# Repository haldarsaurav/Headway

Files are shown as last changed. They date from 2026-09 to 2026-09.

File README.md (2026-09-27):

<p align="center">HEADWAY — a small window on the day</p>

<p align="center"><strong>Train and bus departures, the last few hours at the station, and the weather before I leave home.</strong></p>

## Find your way around

| See it | Build it |
| :--- | :--- |
| **[Screens and five looks →](#take-a-look)** | **[First setup →](#first-setup-in-plain-steps)** |
| **[Photos and video clips →](#the-board-in-use)** | **[FreeCAD cases →](#the-two-cases)** |
| **[Data flow →](#how-it-works)** | **[Wiring and pinout →](#wiring-and-pinout)** |
| **[Electricity use →](#electricity-use)** | **[Reuse and permissions →](#current-state-and-rights)** |

The [screen and icon guide](docs/FEATURE_GUIDE.md) goes page by page. [Firmware and tests](https://github.com/haldarsaurav/Headway_code) live in the code repository.

## Why I built Headway

because why not? 😁

It is a 3.2-inch ILI9341 screen driven by an ESP32-C3 Super Mini. One tap on the board's BOOT button moves to the next page. A three-second hold opens setup. The board reads transport data through [Transitous](https://transitous.org/) and weather from [Open-Meteo](https://open-meteo.com/); it is an independent personal build, not an official operator display.

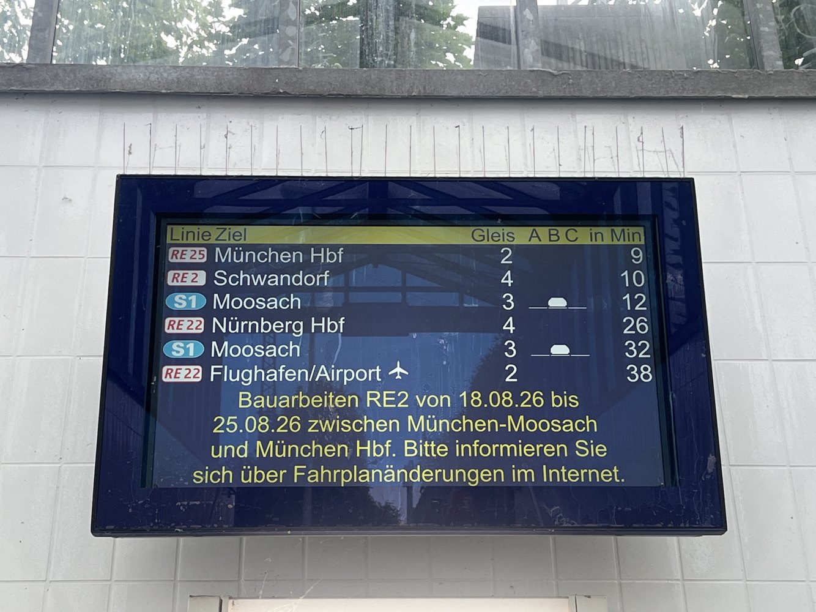
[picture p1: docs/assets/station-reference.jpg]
A real departure board at Freising station that inspired Headway
<p align="center"><br><sub>Sign at my Bahnhof.</sub></p>

## The board in use

The first photo is a powered prototype, photographed at home. It is useful to finally see the physical thing beside the station and weather glances that prompted the project. The second is the same build after dark; these are phone photos, while the crisp screen galleries below are software renders.

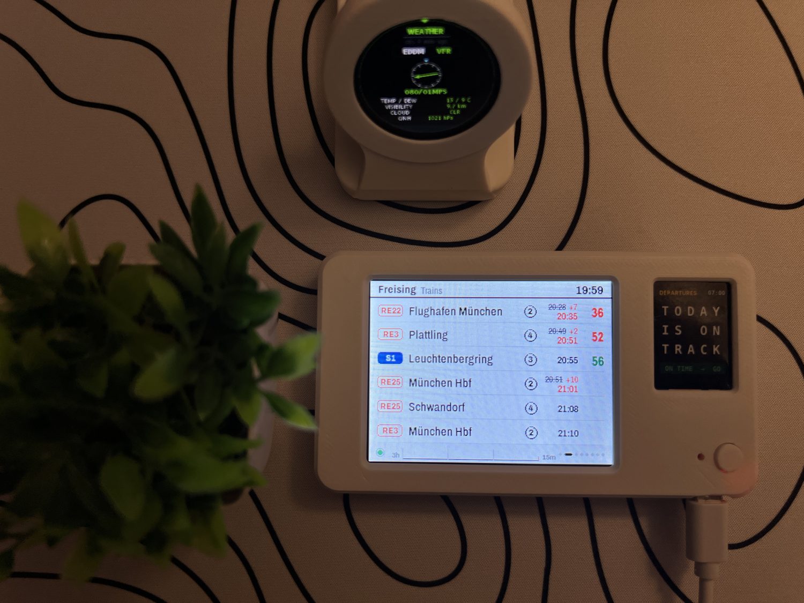
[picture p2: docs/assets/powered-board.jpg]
Powered Headway prototype showing train departures at home
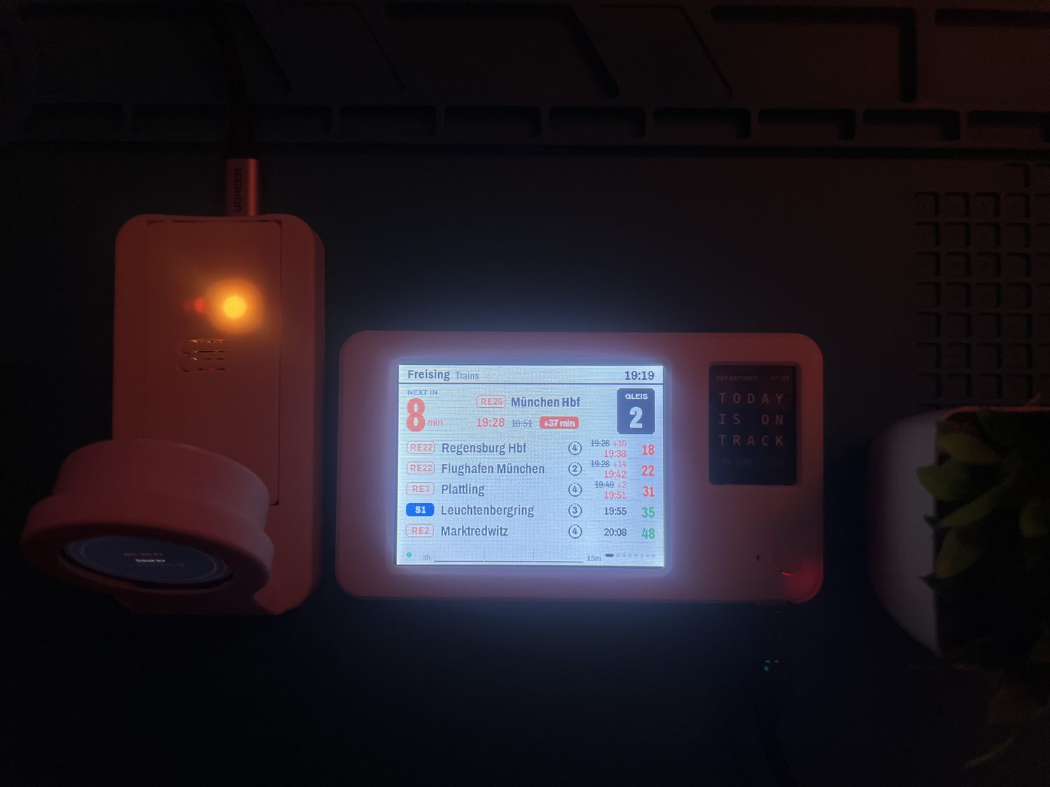
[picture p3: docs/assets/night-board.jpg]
Powered Headway prototype showing departures after dark


The phone videos show all five looks on the powered board, moving from trains to buses and weather. [Play the silent clips](docs/index.html#photos) or open a look directly: [Original](docs/assets/headway-original.webm), [Bahnsteig](docs/assets/headway-bahnsteig.webm), [Amber Matrix](docs/assets/headway-amber-matrix.webm), [Papier](docs/assets/headway-papier.webm), [Split-Flap](docs/assets/headway-split-flap.webm). These are short, compressed excerpts; the full-resolution MOV recordings remain outside this repository.

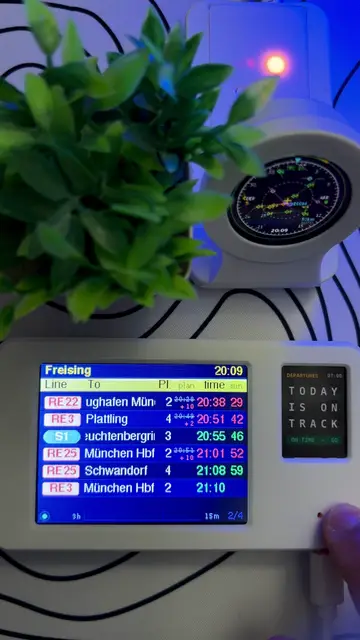
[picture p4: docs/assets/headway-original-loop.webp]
Original look moving through pages on the physical Headway board
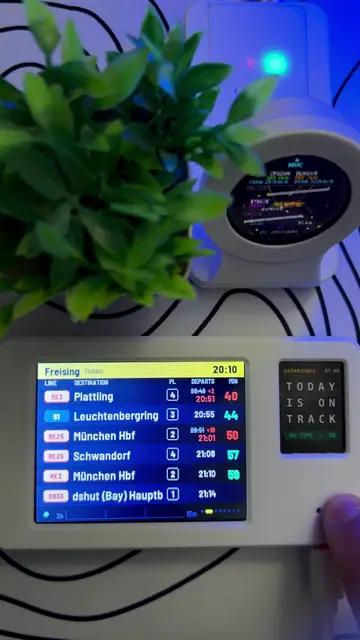
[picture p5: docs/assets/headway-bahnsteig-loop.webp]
Bahnsteig look moving through pages on the physical Headway board
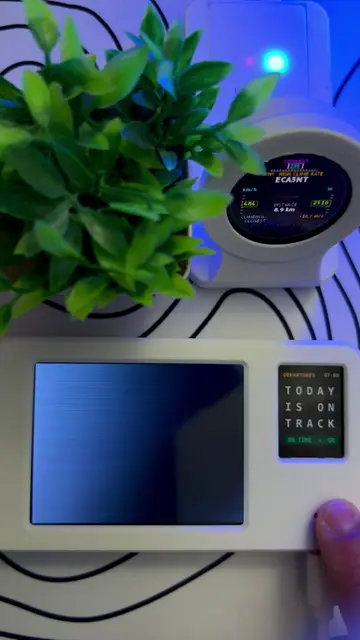
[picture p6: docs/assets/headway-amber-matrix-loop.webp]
Amber Matrix look moving through pages on the physical Headway board
<p align="center">  <br><sub>Original · Bahnsteig · Amber Matrix</sub></p>
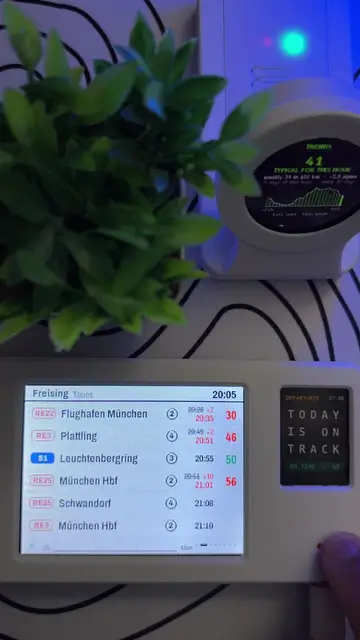
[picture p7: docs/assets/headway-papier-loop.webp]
Papier look moving through pages on the physical Headway board
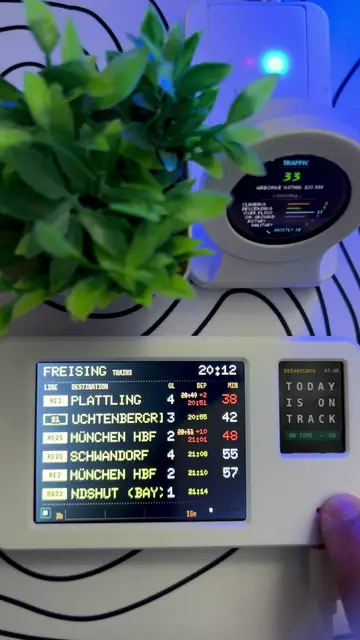
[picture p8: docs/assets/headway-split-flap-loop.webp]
Split-Flap look moving through pages on the physical Headway board
<p align="center"> <br><sub>Papier · Split-Flap</sub></p>

## Take a look

The [screen gallery](docs/index.html#screens) lets you switch **five looks** and the train, bus, weather, outlook and device-setup screens. Its preview images were rendered from the actual drawing code with sample data, not photographed from hardware. Most gallery images are from firmware 1.2.6. Firmware 1.2.7 changed delay-history restart behaviour; 1.2.8 changes the small temperature-history graph on the outlook page, shown separately below.

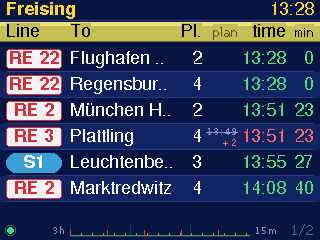
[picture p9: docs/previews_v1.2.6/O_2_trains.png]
Original look train departures
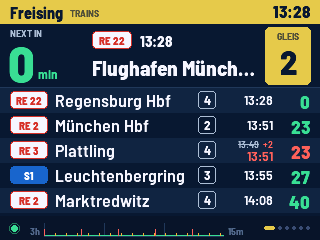
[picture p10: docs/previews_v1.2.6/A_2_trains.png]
Bahnsteig look train departures
<p align="center"> <br><sub>Original and Bahnsteig, using the same sample departures.</sub></p>

<details><summary>Original — the first platform-sign layout</summary>

<p align="center">Original train board software preview<br><sub>Original · train board · sample data</sub></p>

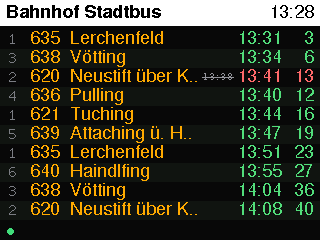
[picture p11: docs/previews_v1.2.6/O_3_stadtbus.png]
Original town bus software preview
<p align="center"><br><sub>Original · town bus · sample data</sub></p>

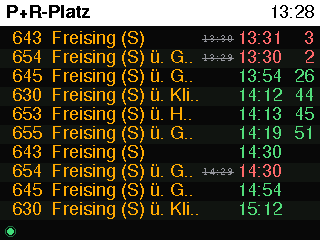
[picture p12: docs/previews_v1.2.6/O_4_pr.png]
Original P+R bus software preview
<p align="center"><br><sub>Original · P+R bus · sample data</sub></p>

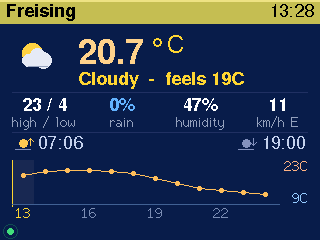
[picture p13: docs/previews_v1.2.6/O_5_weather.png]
Original weather now software preview
<p align="center"><br><sub>Original · weather now · sample data</sub></p>

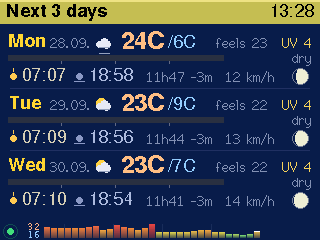
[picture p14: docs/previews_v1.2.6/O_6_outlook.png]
Original three-day outlook software preview
<p align="center"><br><sub>Original · three-day outlook · sample data</sub></p>

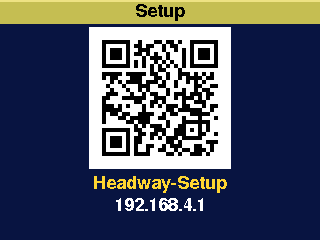
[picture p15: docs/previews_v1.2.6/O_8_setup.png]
Original device setup software preview
<p align="center"><br><sub>Original · device setup · sample data</sub></p>

</details>

<details><summary>Bahnsteig — navy and signal yellow</summary>

<p align="center">Bahnsteig train board software preview<br><sub>Bahnsteig · train board · sample data</sub></p>

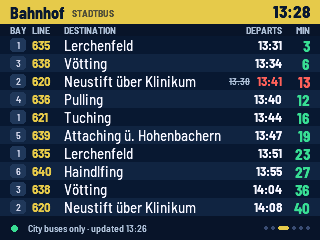
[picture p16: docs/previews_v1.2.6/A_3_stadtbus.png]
Bahnsteig town bus software preview
<p align="center"><br><sub>Bahnsteig · town bus · sample data</sub></p>

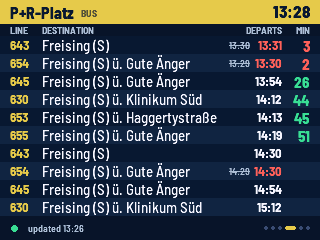
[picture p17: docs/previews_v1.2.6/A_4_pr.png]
Bahnsteig P+R bus software preview
<p align="center"><br><sub>Bahnsteig · P+R bus · sample data</sub></p>

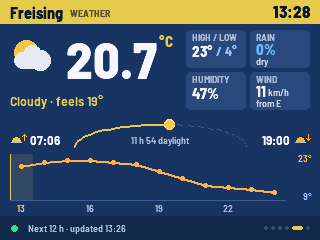
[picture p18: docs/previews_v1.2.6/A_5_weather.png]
Bahnsteig weather now software preview
<p align="center"><br><sub>Bahnsteig · weather now · sample data</sub></p>

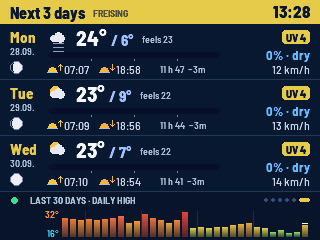
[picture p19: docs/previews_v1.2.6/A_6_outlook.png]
Bahnsteig three-day outlook software preview
<p align="center"><br><sub>Bahnsteig · three-day outlook · sample data</sub></p>

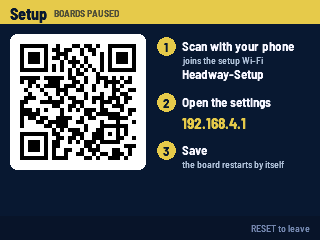
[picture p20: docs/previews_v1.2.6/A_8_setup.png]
Bahnsteig device setup software preview
<p align="center"><br><sub>Bahnsteig · device setup · sample data</sub></p>

</details>

<details><summary>Amber Matrix — electronic display dots</summary>

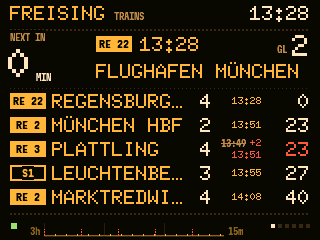
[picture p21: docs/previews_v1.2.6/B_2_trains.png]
Amber Matrix train board software preview
<p align="center"><br><sub>Amber Matrix · train board · sample data</sub></p>

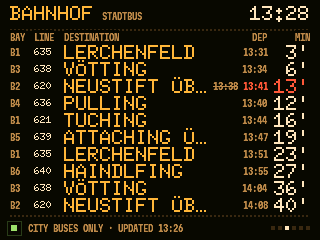
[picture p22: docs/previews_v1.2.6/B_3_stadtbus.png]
Amber Matrix town bus software preview
<p align="center"><br><sub>Amber Matrix · town bus · sample data</sub></p>

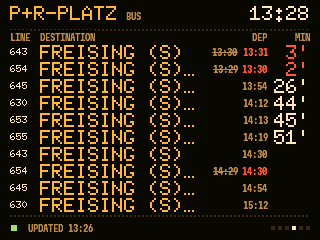
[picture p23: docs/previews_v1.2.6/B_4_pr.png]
Amber Matrix P+R bus software preview
<p align="center"><br><sub>Amber Matrix · P+R bus · sample data</sub></p>

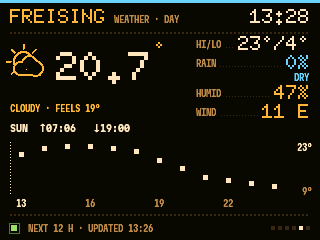
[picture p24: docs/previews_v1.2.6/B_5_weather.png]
Amber Matrix weather now software preview
<p align="center"><br><sub>Amber Matrix · weather now · sample data</sub></p>

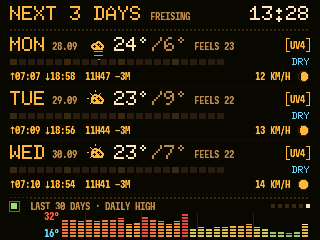
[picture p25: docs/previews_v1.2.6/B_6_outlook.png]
Amber Matrix three-day outlook software preview
<p align="center"><br><sub>Amber Matrix · three-day outlook · sample data</sub></p>

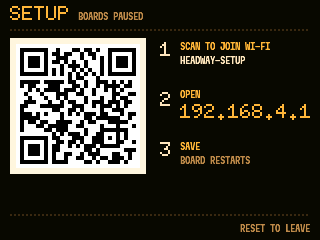
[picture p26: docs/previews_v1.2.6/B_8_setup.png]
Amber Matrix device setup software preview
<p align="center"><br><sub>Amber Matrix · device setup · sample data</sub></p>

</details>

<details><summary>Papier — light paper and ink</summary>

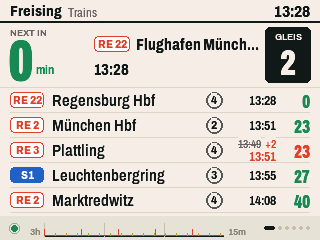
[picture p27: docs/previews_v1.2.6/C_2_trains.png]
Papier train board software preview
<p align="center"><br><sub>Papier · train board · sample data</sub></p>

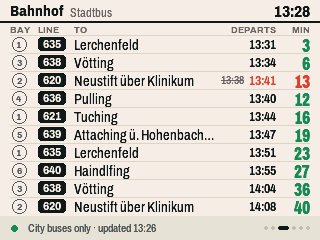
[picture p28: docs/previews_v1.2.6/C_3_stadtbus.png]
Papier town bus software preview
<p align="center"><br><sub>Papier · town bus · sample data</sub></p>

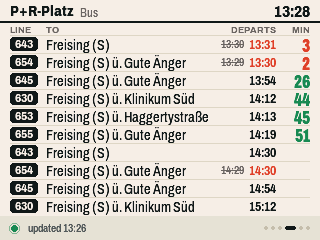
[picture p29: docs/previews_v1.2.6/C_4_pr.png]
Papier P+R bus software preview
<p align="center"><br><sub>Papier · P+R bus · sample data</sub></p>

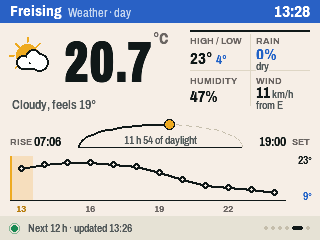
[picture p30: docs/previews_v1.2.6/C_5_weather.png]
Papier weather now software preview
<p align="center"><br><sub>Papier · weather now · sample data</sub></p>

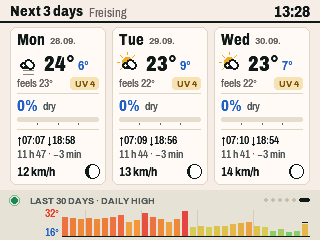
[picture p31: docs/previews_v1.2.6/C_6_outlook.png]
Papier three-day outlook software preview
<p align="center"><br><sub>Papier · three-day outlook · sample data</sub></p>

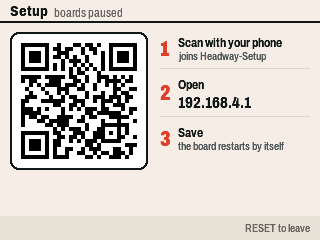
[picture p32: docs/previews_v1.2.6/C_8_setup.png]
Papier device setup software preview
<p align="center"><br><sub>Papier · device setup · sample data</sub></p>

</details>

<details><summary>Split-Flap — mechanical tile lettering</summary>

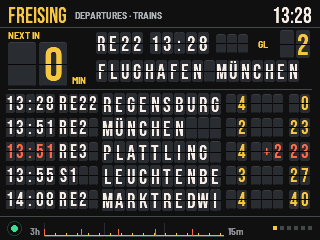
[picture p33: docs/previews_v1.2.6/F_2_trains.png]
Split-Flap train board software preview
<p align="center"><br><sub>Split-Flap · train board · sample data</sub></p>

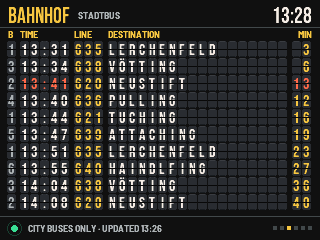
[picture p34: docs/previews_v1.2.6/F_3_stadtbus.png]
Split-Flap town bus software preview
<p align="center"><br><sub>Split-Flap · town bus · sample data</sub></p>

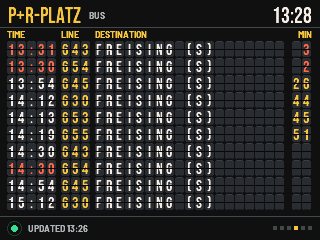
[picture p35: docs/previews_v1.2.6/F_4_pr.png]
Split-Flap P+R bus software preview
<p align="center"><br><sub>Split-Flap · P+R bus · sample data</sub></p>

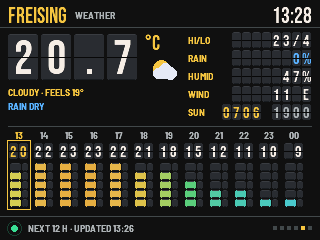
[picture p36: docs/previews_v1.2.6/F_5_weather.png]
Split-Flap weather now software preview
<p align="center"><br><sub>Split-Flap · weather now · sample data</sub></p>

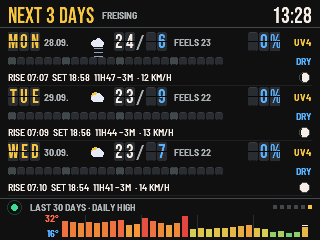
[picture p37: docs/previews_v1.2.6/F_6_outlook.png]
Split-Flap three-day outlook software preview
<p align="center"><br><sub>Split-Flap · three-day outlook · sample data</sub></p>

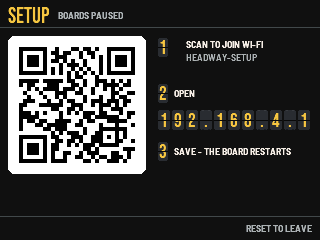
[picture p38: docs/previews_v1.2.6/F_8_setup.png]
Split-Flap device setup software preview
<p align="center"><br><sub>Split-Flap · device setup · sample data</sub></p>

</details>

The page order is **trains → Bahnhof Stadtbus → P+R-Platz → weather now → three-day outlook**. Trains can occupy one to four screens depending on the returned services. Automatic page changes and scrolling long destinations are separate, optional settings. The [full guide](docs/FEATURE_GUIDE.md) explains every badge, time, colour, icon, graph mark, status message and control with examples.

### Temperature history in 1.2.8

The graph at the bottom of the three-day outlook now draws a bar from **each day's low to its high**. The two numbers beside it are the coldest low and warmest high in the displayed window. A day with no reported low becomes a short mark at its high. This comparison uses current PC renders with sample weather data; the phone videos above show the physical board running earlier screens.

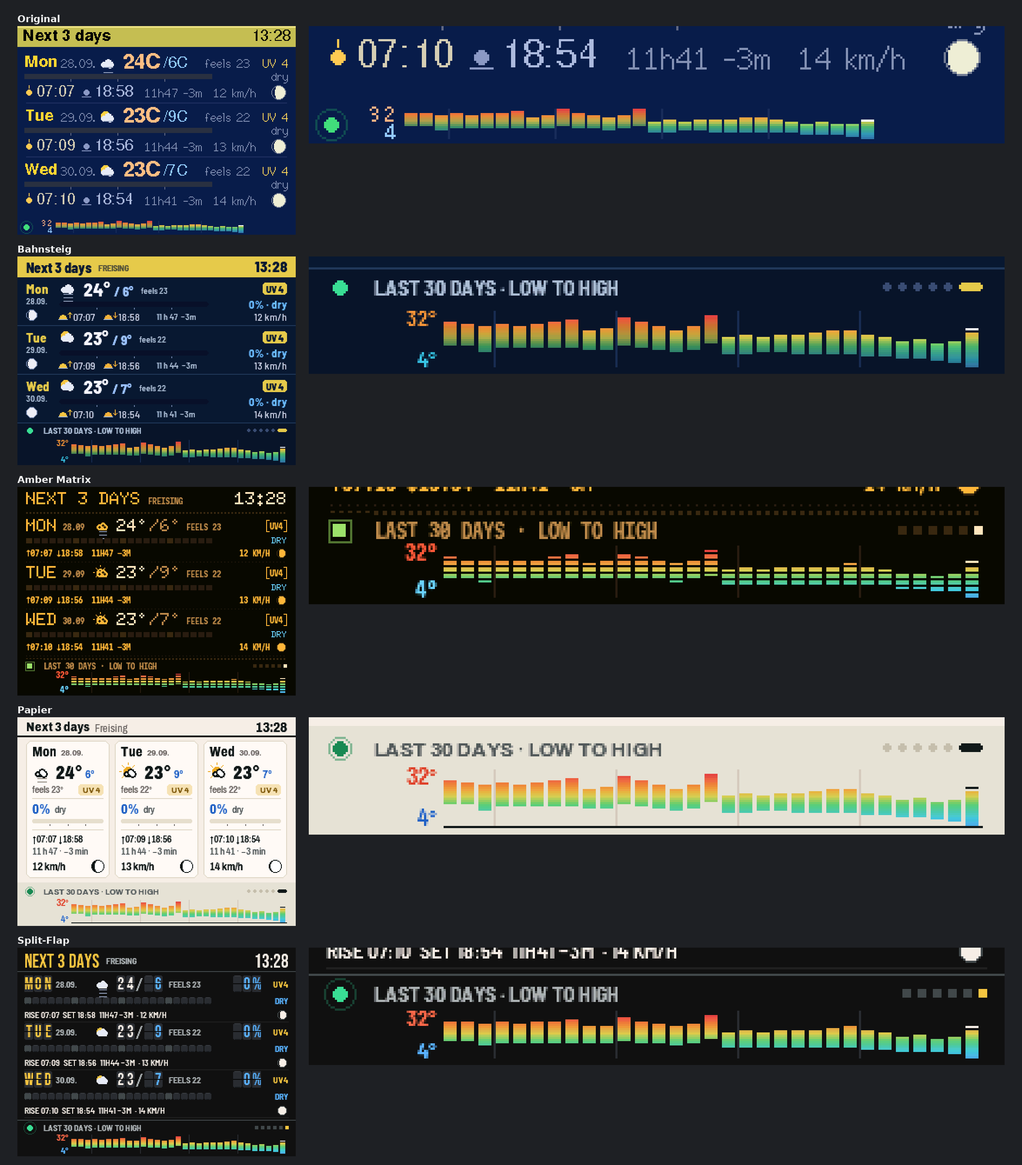
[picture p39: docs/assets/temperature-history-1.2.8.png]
Firmware 1.2.8 low-to-high temperature history shown in all five Headway looks
<p align="center"><br><sub>The updated outlook graph in all five looks. Click for the full-size image.</sub></p>

### The history strip

The train footer shows 180 elapsed-minute slots. It averages positive reported lateness among comparable realtime departures due within the next hour of each fetched board. Red marks show cancellations separately; grey marks warn of incomplete realtime coverage; gaps mean no usable sample. It is a quick view of recent feed reports, not a station-wide punctuality score. Since firmware 1.2.7 the strip survives a software restart, with a gap for the restart, but loses its history when power is removed. [Read the graph definition](docs/DELAY_GRAPH.md).

## How it works

```mermaid
flowchart TD
    T[Transitous<br/>trains and local buses] --> E[ESP32-C3<br/>fetch and validate]
    W[Open-Meteo<br/>weather and forecast] --> E
    E --> H{Each feed healthy?}
    H -->|Fresh data| S[Draw page and update history]
    H -->|Unavailable or incomplete| G[Show feed state and keep graph gaps]
    S --> D[3.2-inch screen<br/>one-button navigation]
    G --> D
    B[BOOT button<br/>hold 3 seconds] --> P[Setup portal]
    P -->|Save and restart| E
```

The feeds have separate health states. A working weather refresh cannot hide a failed train refresh. During an outage, countdowns still advance and expired rows disappear; retained readings may become stale. [Status and remaining hardware checks](docs/PROJECT_STATUS.md).

## First setup, in plain steps

1. Power the board by USB-C. On first use, scan the on-screen QR to join **Headway-Setup**.
2. Scan the settings QR or open **http://192.168.4.1/** on that Wi-Fi network.
3. Choose a 2.4 GHz network, automatic or typed weather town, one of the five looks, and optional page changes and scrolling. Press **Save and restart**.
4. Tap BOOT for the next page; hold it for three seconds to reopen setup. Hold it only after startup, because GPIO 9 is a boot strap pin.

The portal presents its controls in separate cards:

- **Wi-Fi:** choose a scanned 2.4 GHz network or type its name; leaving the password empty keeps the saved one for the same network.
- **Weather place:** detect an approximate location from the connection, or enter a town. The Freising transport stops stay fixed.
- **Look:** Original is the default; the other four choices preview immediately in the portal, then apply to the board after Save.
- **Pages and names:** automatic page changes and destination scrolling are independent and off by default; set the page interval when automatic changes are on.
- **Save and restart:** stores the settings and restarts. The delay graph keeps recent readings across that software restart, leaving a gap while setup was open.
- **Start over:** asks a second time, then forgets Wi-Fi and every setting and empties the history.

The [feature guide](docs/FEATURE_GUIDE.md#boot-controls-and-setup) covers the QR screens, controls and troubleshooting.

## The two cases

**Model A · wall, Rev9.** The slim case is meant for the morning route through the home. **Model B · desk, rev2.** The separate stand tips the screen back 15°; USB-C enters from the right. Both current designs use four M2.5 heat-set inserts and four countersunk screws. Using threaded inserts was a first for me; I wanted a back I could open without wearing out a plastic screw hole. I have a powered prototype in a printed enclosure now; the exact fit of the latest CAD revisions still needs checking.

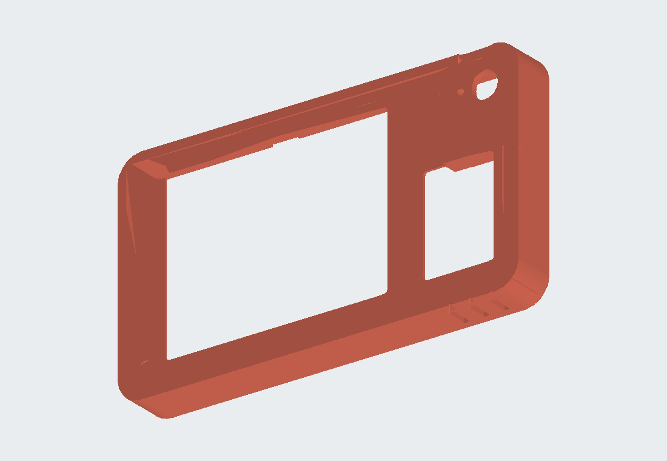
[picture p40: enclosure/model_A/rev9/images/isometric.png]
Model A wall case isometric CAD view
<p align="center"> Model B desk case isometric CAD view<br><sub>Current shell geometry rendered from the FreeCAD exports, not physical-product photos.</sub></p>

### On the slicer bed

These are actual slicer screenshots: Model A has the shell and back plate, while Model B also has its separate desk stand. The orange lines are sliced layers, not a photo of the print.

<p align="center">Model A shell and back plate arranged in a slicer Model B shell, back plate and stand arranged in a slicer<br><sub>Model A · wall / Model B · desk</sub></p>

[Full-size Model A slicer screenshot](enclosure/slicer/modelA.png) · [Full-size Model B slicer screenshot](enclosure/slicer/modelB.png)

Both have [isometric, front, back, top and side views](enclosure/README.md), plus back-plate views and a separate stand view for Model B. The [FreeCAD sources and printable parts](enclosure/README.md) are kept with each model. These photos show printed revisions and the loose parts before assembly; they do not prove the latest CAD fit.

<p align="center">Headway case parts on the printer bed under warm light Six printed Headway shell revisions laid out on a blue mat Headway enclosure, display, ESP32-C3 and fasteners before assembly<br><sub>Print in progress, revisions, and the parts laid out before assembly.</sub></p>

The close assembly photo shows **three brass heat-set inserts visible in the front shell**, beside the wired ESP32-C3, display and screws. That small hardware detail is new territory for me, and it makes the enclosure easier to open again.

<p align="center">Close assembly view showing three brass threaded inserts in the printed front shell, ESP32-C3, display and screws<br><sub>The threaded inserts are visible in the white front shell.</sub></p>

## Wiring and pinout

The circuit is two boards and nine wires. The display uses the C3's 3V3, GND, 5V and GPIO 3/4/5/6/7/10; BOOT on GPIO 9 is the control. [Pinout diagram and wiring table](docs/SCHEMATIC.md) · [ESP32-C3 module datasheet](https://documentation.espressif.com/esp32-c3-mini-1_datasheet_en.html) · [MSP3218 display manual and pinout](https://www.lcdwiki.com/res/MSP3218/3.2inch_SPI_Module_MSP3218_User_Manual_EN.pdf). Check the labels on your actual boards before powering them; Super Mini variants differ. The project drawing uses 5 V on the display LED pin, while the MSP3218 manual describes 3.3 V for always-on backlighting, so verify that connection on the exact module.

## Electricity use

| Assumption | Estimate for continuous use |
| :--- | ---: |
| Average draw | **0.75 W** |
| Energy over 24 hours | **0.018 kWh** |
| Energy over one year | **6.57 kWh** |
| At an example €0.30/kWh | **about €1.97/year** |

These are estimates, not a documented power-meter reading for this revision. A USB meter check is still on my list; the price example excludes standing charges.

## Current state and rights

Firmware **1.2.8** is in the [code repository](https://github.com/haldarsaurav/Headway_code), along with tests, preview tooling, build instructions and the changelog. The source project reports PC renders of every look and regression checks; the nine setup scenarios passed again in this repository sync. I have not compiled or flashed 1.2.8 on the ESP32 here. The current CAD also needs a full fit check. See [project status](docs/PROJECT_STATUS.md) for the precise scope.

Copyright 2026 **Saurav Haldar**. This public repository is for viewing the project. Use and reuse require permission under the [licence](LICENSE); the [permission guide](docs/PERMISSIONS.md) explains the request process. Third-party transport, weather and font material retains its own terms.

Please do not scrape the writing, diagrams, images, CAD, code or documented project plan into AI datasets or use them to recreate Headway without my written permission. The [AI-use policy](AI_POLICY.md) gives the full request path and its legal limits.

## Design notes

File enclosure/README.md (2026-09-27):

# The two Headway cases

[Back to the project](../README.md) · [Interactive CAD gallery](../docs/index.html#enclosures)

Both current designs come from editable FreeCAD models. The gallery images below were rendered from those models' exported STL geometry. They show the design, not an assembled or fit-verified device. The [main README](../README.md#the-two-cases) also shows real print iterations and the parts before assembly; its [powered-board photos](../README.md#the-board-in-use) show a physical prototype, without proving the latest CAD revision fits.

## Model A · wall, Rev9

This is the case I plan to place near my bathroom mirror or by the front door. It has a display window, a small picture-card opening and access to the BOOT key. Rev9 adds a fourth screw boss and stronger ESP32 ribs. Four M2.5 heat-set inserts and countersunk screws make the back removable. The three display screws also clamp the display; the fourth closes the far corner.

<p align="center">Model A isometric CAD view<br><sub>Isometric front shell</sub></p>

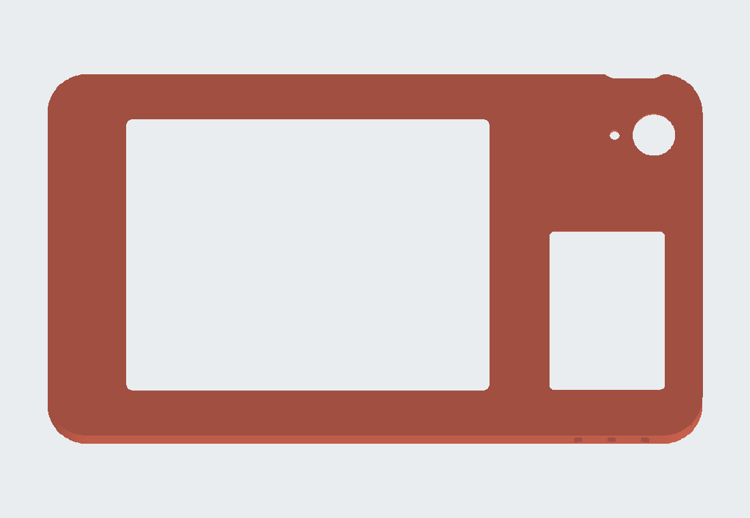
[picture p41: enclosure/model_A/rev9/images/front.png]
Model A front CAD view
<p align="center"><br><sub>Front</sub></p>
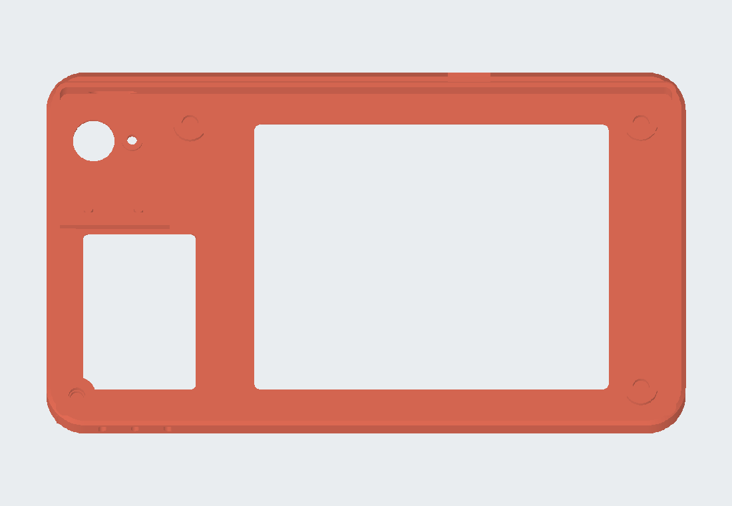
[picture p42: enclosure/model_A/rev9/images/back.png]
Model A back CAD view
<p align="center"><br><sub>Back / inside of shell</sub></p>
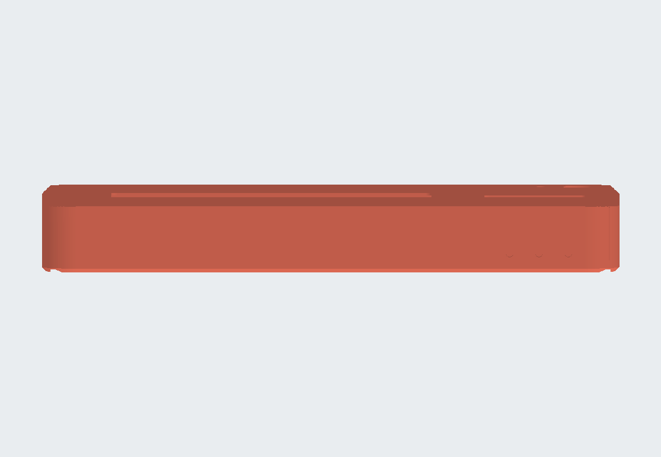
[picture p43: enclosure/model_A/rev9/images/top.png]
Model A top CAD view
<p align="center"><br><sub>Top</sub></p>
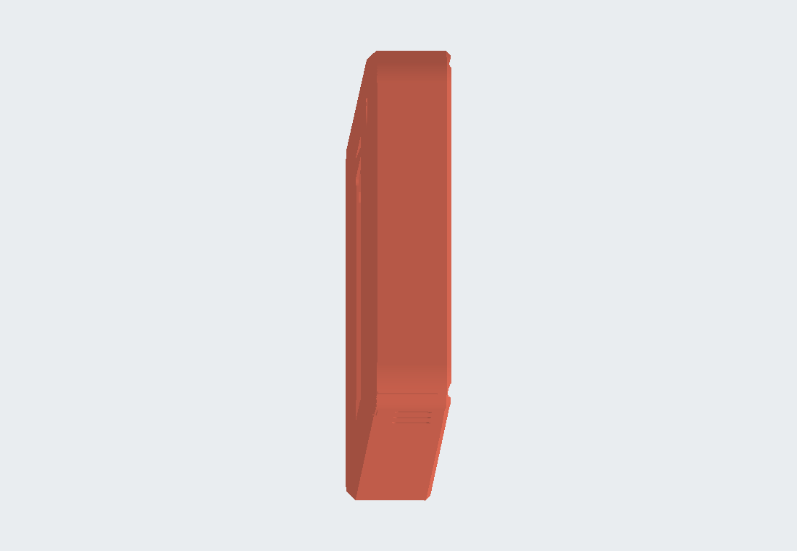
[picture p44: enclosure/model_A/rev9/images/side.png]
Model A side CAD view
<p align="center"><br><sub>Side</sub></p>
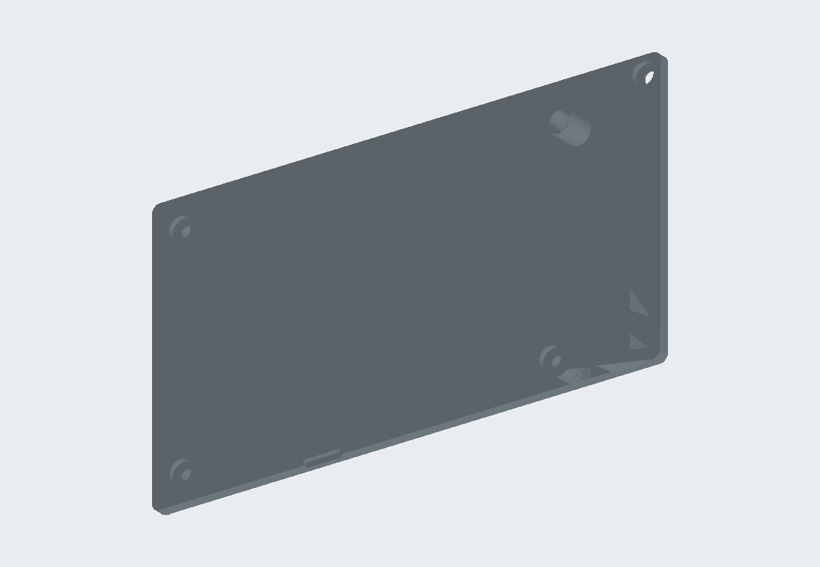
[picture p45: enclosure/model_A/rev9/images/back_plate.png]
Model A separate back plate CAD view
<p align="center"><br><sub>Separate back plate</sub></p>

[FreeCAD model](model_A/rev9/Headway_enclosure_rev9.FCStd) · [STEP](model_A/rev9/Headway_enclosure_rev9.step) · [parts, print orientation and assembly](model_A/rev9/README_REV9.md)

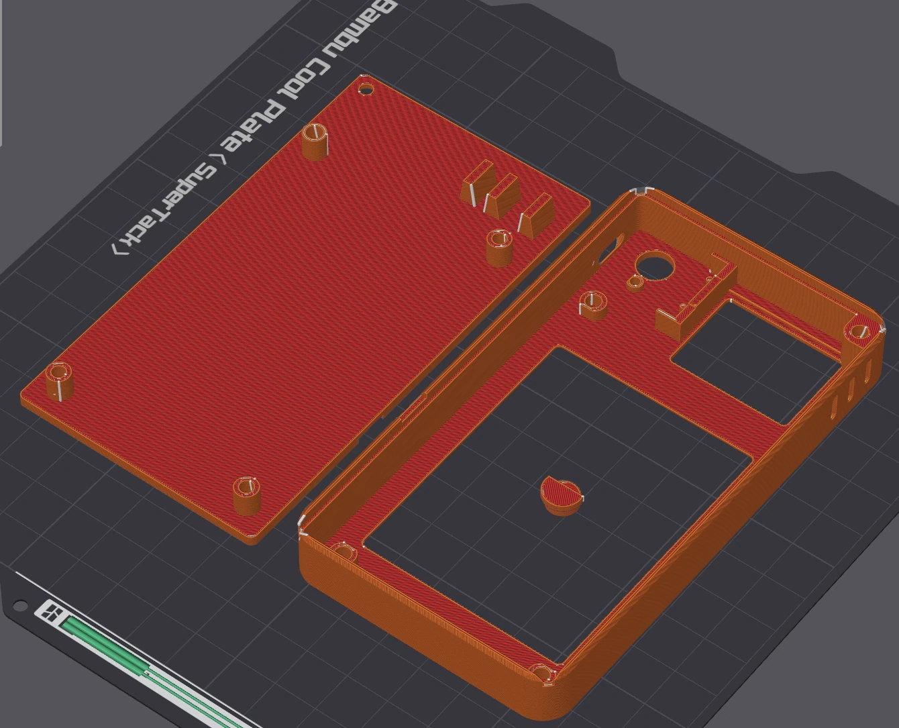
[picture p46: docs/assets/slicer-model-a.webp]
Model A shell and back plate arranged on a slicer bed
<p align="center"><br><sub>Model A in the slicer: shell and back plate.</sub></p>

[Full-size slicer screenshot](slicer/modelA.png)

## Model B · desk, rev2

Model B puts the board on my desk. Its separate stand leans the screen back 15°. The USB-C cable comes in from the right and the case can lift out of the stand. Rev2 carries the same four-insert closure as Model A; the stand is a separate print.

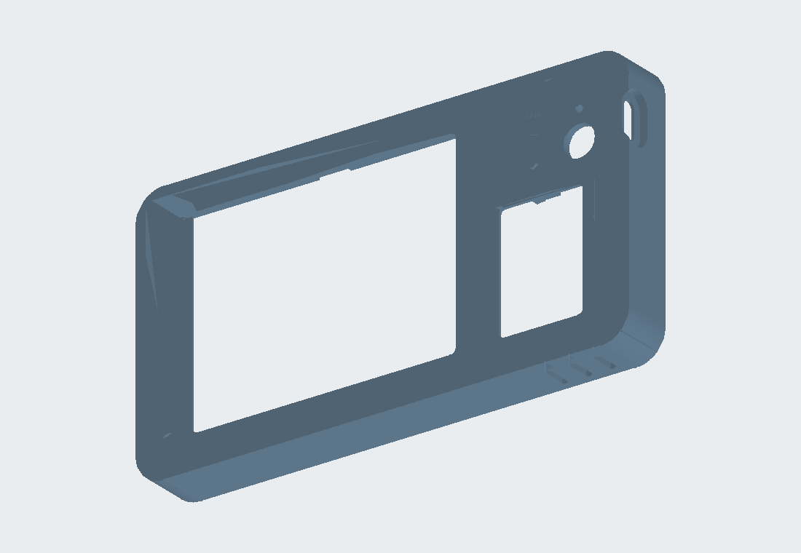
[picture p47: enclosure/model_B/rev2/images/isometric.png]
Model B isometric CAD view
<p align="center"><br><sub>Isometric front shell</sub></p>

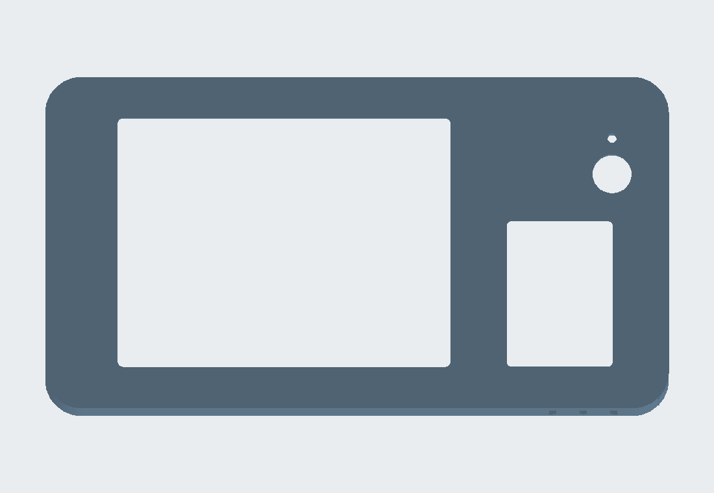
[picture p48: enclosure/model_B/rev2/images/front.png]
Model B front CAD view
<p align="center"><br><sub>Front</sub></p>
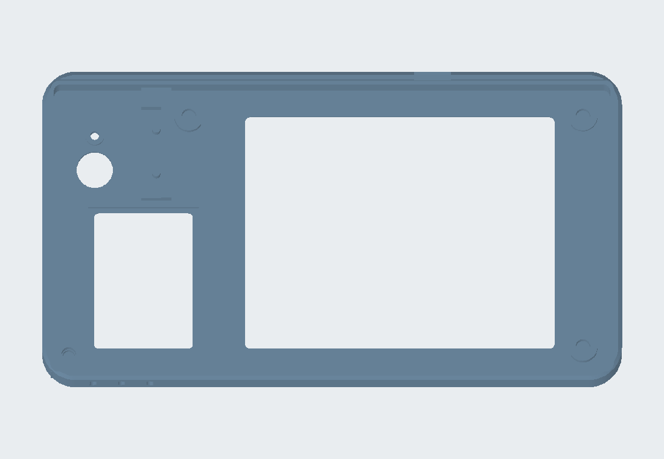
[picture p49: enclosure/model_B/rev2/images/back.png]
Model B back CAD view
<p align="center"><br><sub>Back / inside of shell</sub></p>
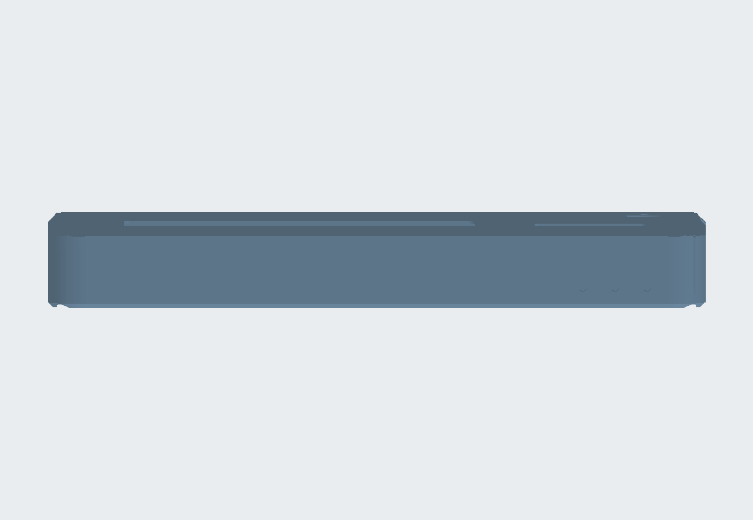
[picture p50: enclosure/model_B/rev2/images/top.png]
Model B top CAD view
<p align="center"><br><sub>Top</sub></p>
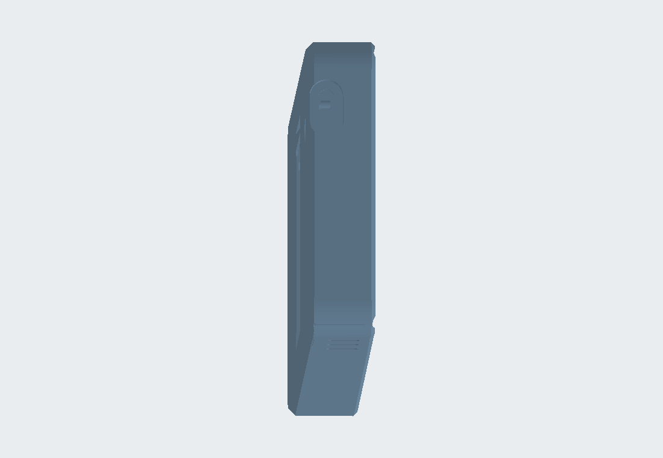
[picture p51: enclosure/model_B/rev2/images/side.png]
Model B side CAD view
<p align="center"><br><sub>Side</sub></p>
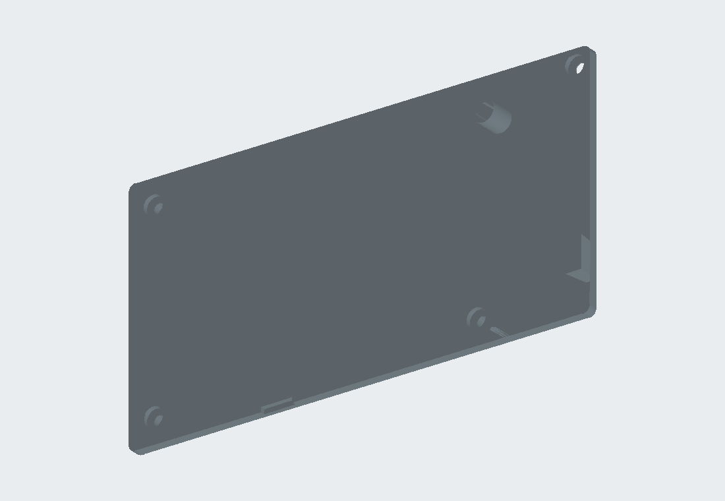
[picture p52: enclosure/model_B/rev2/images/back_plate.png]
Model B separate back plate CAD view
<p align="center"><br><sub>Separate back plate</sub></p>
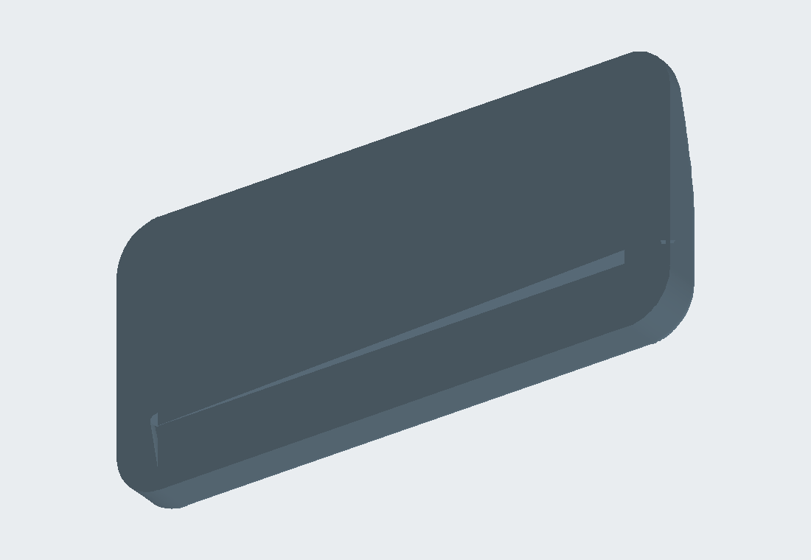
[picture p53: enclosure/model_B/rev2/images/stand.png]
Model B separate stand CAD view
<p align="center"><br><sub>15° desk stand</sub></p>

[FreeCAD model](model_B/rev2/Headway_desk_rev2.FCStd) · [STEP](model_B/rev2/Headway_desk_rev2.step) · [parts, print orientation and assembly](model_B/rev2/README_DESK_REV2.md)

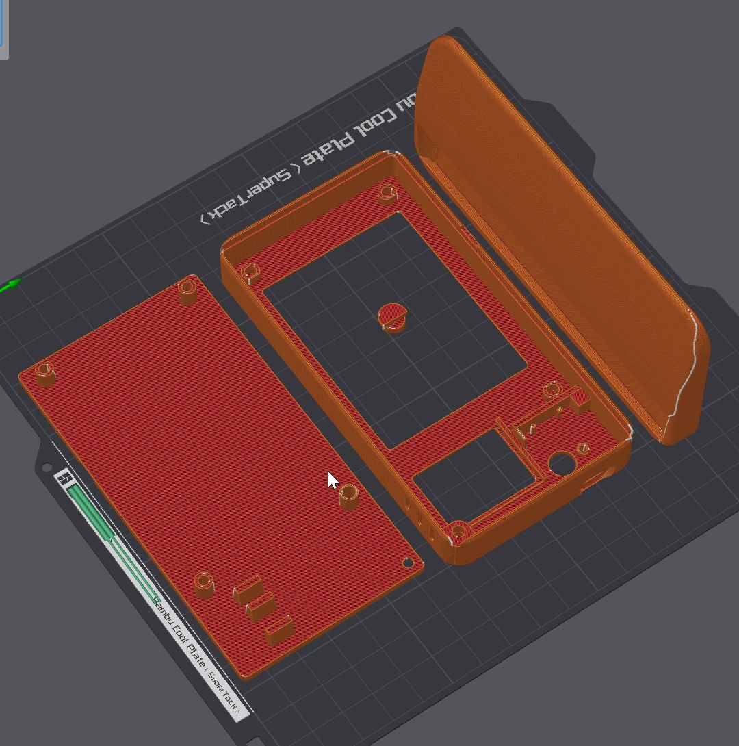
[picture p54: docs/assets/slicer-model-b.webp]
Model B shell, back plate and desk stand arranged on a slicer bed
<p align="center"><br><sub>Model B in the slicer: shell, back plate and separate stand.</sub></p>

[Full-size slicer screenshot](slicer/modelB.png)

## About the printed parts

Using heat-set threaded inserts was a first for me. I like being able to open the case again without cutting a fresh screw thread in the plastic each time. The source notes specify four M2.5 × 3 × 3.5 inserts, three M2.5 × 12 countersunk screws for the display posts and one M2.5 × 6 for the corner boss. The optional fit-test STL is intended to check the window before a full shell print. Print settings and insertion steps are in each model's README.

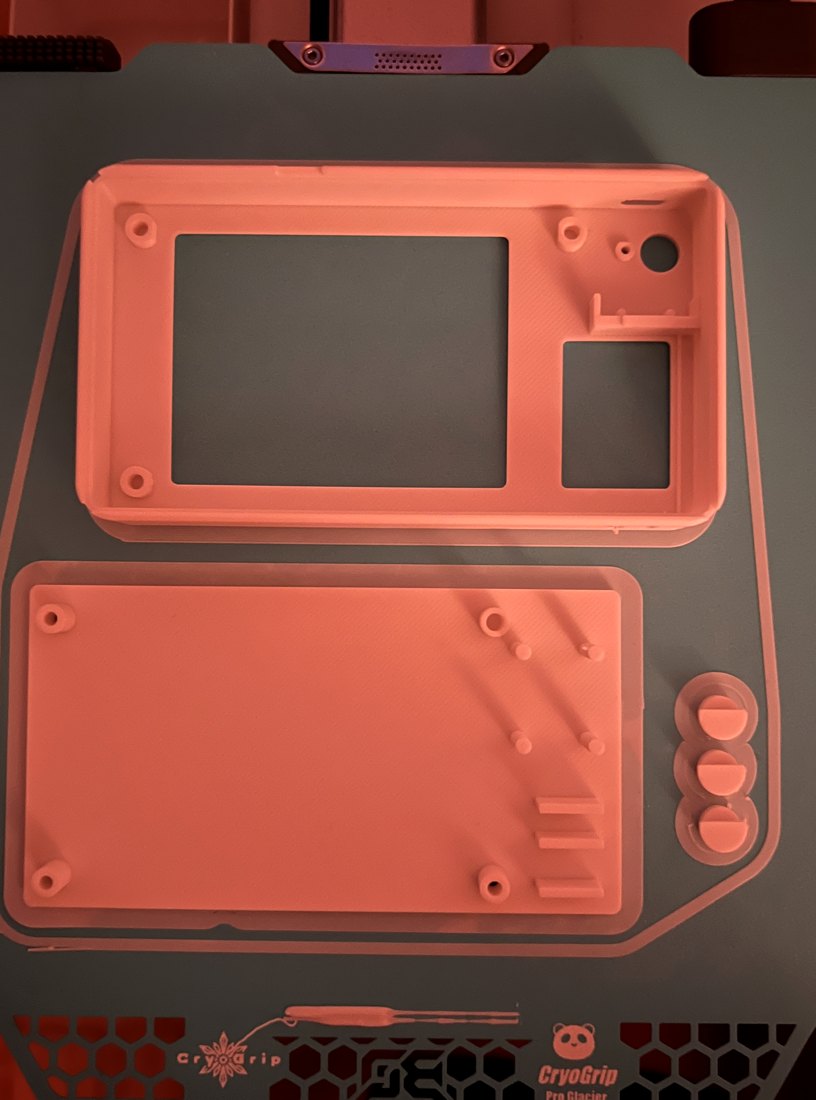
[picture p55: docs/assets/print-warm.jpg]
Case parts on the printer bed
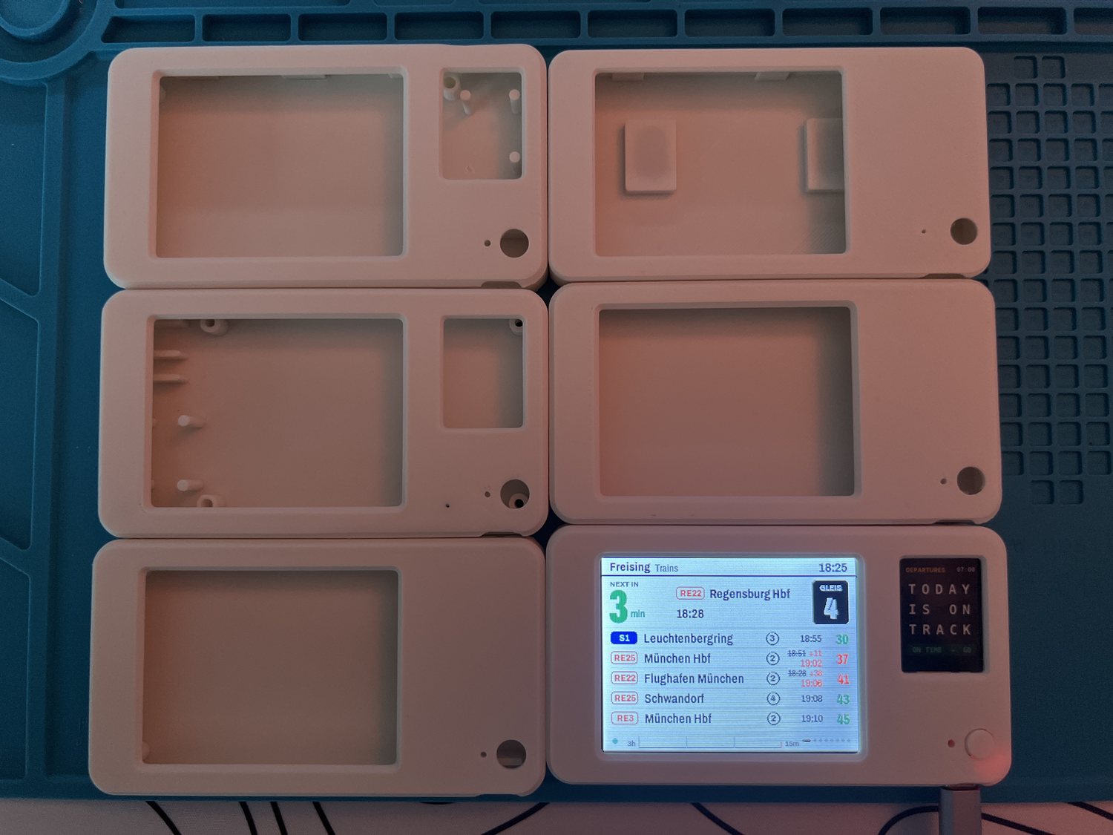
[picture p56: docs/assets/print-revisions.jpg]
Printed enclosure iterations arranged on a mat
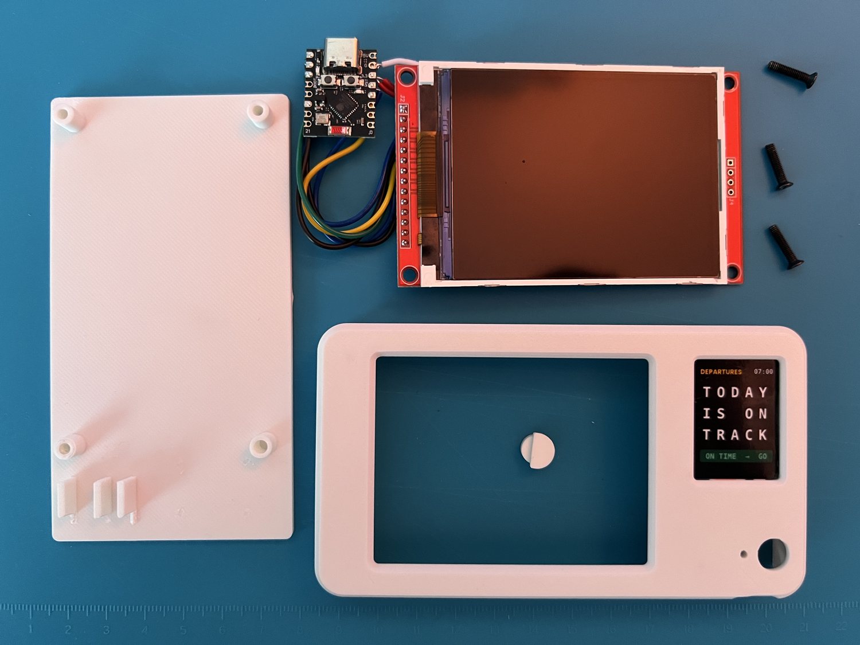
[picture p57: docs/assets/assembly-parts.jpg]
Shell, display, ESP32-C3 and fasteners before assembly
<p align="center">  <br><sub>Print in progress, iterations and parts laid out before assembly.</sub></p>

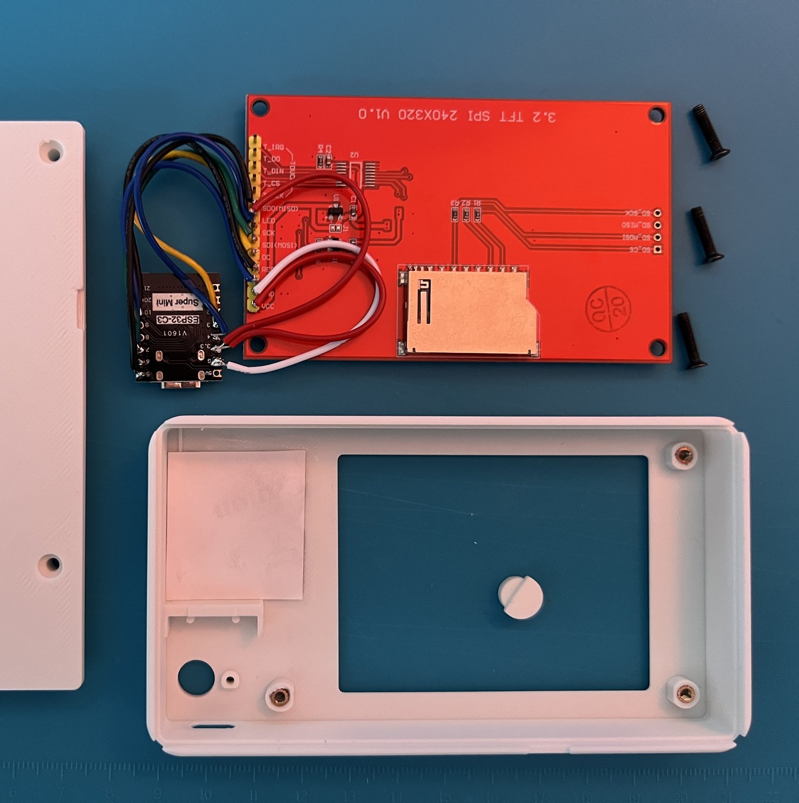
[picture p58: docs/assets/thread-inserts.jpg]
Three brass threaded inserts visible in the printed front shell, beside the ESP32-C3, display and screws
<p align="center"><br><sub>Three of the front-shell inserts are visible in this assembly photo.</sub></p>

The CAD geometry has had script-level overlap checks, but the current enclosure revisions still need a complete physical fit, screw engagement and heat check. The image renderer is in [render_views.py](render_views.py), so the five-view sets can be recreated from the FreeCAD-exported STL files.

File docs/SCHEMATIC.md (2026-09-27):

# Wiring and pinout

Headway Rev1.2 / firmware v1.2.8 — the whole circuit is two boards and nine wires.
No resistors, no level shifters, no extra button: MODE is the BOOT button already on the ESP32-C3.

<p align="center">Logical nine-wire pinout from ESP32-C3 Super Mini to the MSP3218 display<br><sub>Logical wiring map for this build; check the labels on the boards in your hands.</sub></p>

The [Espressif ESP32-C3 module datasheet](https://documentation.espressif.com/esp32-c3-mini-1_datasheet_en.html) covers GPIO and boot behaviour. The [MSP3218 user manual](https://www.lcdwiki.com/res/MSP3218/3.2inch_SPI_Module_MSP3218_User_Manual_EN.pdf) gives the display connector pinout; its [product page](https://www.lcdwiki.com/3.2inch_SPI_Module_ILI9341_SKU:MSP3218) links further display documents. Super Mini carrier boards can differ, so these sources supplement rather than replace the actual silkscreen.

```
                         USB-C  (5 V power + serial + flashing)
                           ║
        ┌──────────────────╨──────────────────┐
        │         ESP32-C3  SUPER MINI        │
        │                                     │
        │  3V3  ●─────────────────────────────┼──────────●  VCC          ┐
        │  GND  ●─────────────────────────────┼──────────●  GND          │
        │  5V   ●─────────────────────────────┼──────────●  LED          │  (backlight)
        │                                     │                          │
        │  GPIO 7   ●── CS ───────────────────┼──────────●  CS           │  3.2"  SPI TFT
        │  GPIO 10  ●── RESET ────────────────┼──────────●  RESET        │  ILI9341
        │  GPIO 3   ●── DC / RS ──────────────┼──────────●  DC / RS      │  240 x 320
        │  GPIO 6   ●── MOSI (SPI2) ──────────┼──────────●  SDI / MOSI   │  (landscape
        │  GPIO 4   ●── SCK  (SPI2) ──────────┼──────────●  SCK          │   320 x 240)
        │  GPIO 5   ●── MISO (SPI2) ──────────┼──────────●  SDO / MISO   │
        │                                     │                          │
        │  GPIO 9   ●── [BOOT] ── GND         │           T_CLK  ┐       │
        │           (= MODE button,           │           T_CS   │       │
        │            internal pull-up)        │           T_DIN  │ not   │
        │                                     │           T_DO   │ con-  │
        │  [RST]  hardware reset              │           T_IRQ  │ nected│
        │                                     │           SD_*   ┘       ┘
        └─────────────────────────────────────┘
```

## Pin table

| TFT pin | ESP32-C3 | Signal | Notes |
|---|---|---|---|
| VCC | **3V3** | logic supply | ⚠️ must be 3.3 V — on 5 V the panel lights but stays **white** |
| GND | GND | ground | |
| CS | GPIO 7 | SPI chip select | |
| RESET | GPIO 10 | panel reset | |
| DC / RS | GPIO 3 | data / command | |
| SDI / MOSI | GPIO 6 | SPI data out | SPI2 host |
| SCK | GPIO 4 | SPI clock | 20 MHz write, 8 MHz read |
| SDO / MISO | GPIO 5 | SPI data in | lets LovyanGFX read the panel back |
| LED | 5V | backlight | always on; biggest single power draw |
| T_* / SD_* | — | touch + SD card | not used |

**Backlight check:** this project's wiring plan puts the module's `LED` pin on the board's 5 V rail. The [MSP3218 manual](https://www.lcdwiki.com/res/MSP3218/3.2inch_SPI_Module_MSP3218_User_Manual_EN.pdf) describes 3.3 V for an always-on backlight. Confirm the exact module's backlight circuit and rating before copying the 5 V connection; the published diagram records this build's wiring, not a universal module recommendation.

| On the ESP32 board | GPIO | Used as |
|---|---|---|
| BOOT button | 9 | **MODE** — tap = next page, hold 3 s = setup |
| RST button | — | restart (hardware) |

## Power

```
USB 5 V ──┬── ESP32-C3 on-board 3.3 V regulator ──► ESP32-C3 + TFT VCC (logic)
          └──────────────────────────────────────► TFT LED (backlight)
```

- Power it from a decent USB supply or a PC port. The Wi-Fi TX burst on top of the backlight
  can dip the rail on a weak cable/breadboard — the board then logs **"brown-out (power dip)"**
  as its last restart reason (shown in red on the boot splash and on the setup page).
- GPIO 9 is a **strapping pin**: holding BOOT *while plugging in or pressing RST* puts the chip
  into flash-download mode (dark screen). Press MODE only after the splash is up.

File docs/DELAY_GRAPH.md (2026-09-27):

# Train delay graph — Rev1.1

## What it measures

Each minute is a snapshot of the fetched Freising board, across all train pages. Select services
whose returned departure time is from now through 60 minutes ahead (inclusive). The firmware
retains at most 24 trains, so this is a bounded board sample, not a complete station census.

For each non-cancelled service, require `realTime = true` and valid actual and scheduled departure
timestamps. Lateness is `max(actual - scheduled, 0)` in seconds. Average those seconds over the
eligible services, then round once to the nearest tenth of a minute. Early departures contribute
zero lateness. Timetable-only entries and entries without comparable timestamps do not dilute
the mean. With no eligible services, the reading is missing, not zero.

Examples: 90 and 180 seconds average to 2.3 minutes after rounding. A two-minute early train and
a two-minute late train average to 1.0 minute of lateness. One cancellation and one on-time
realtime train produce a zero-height green reading plus a cancellation marker, not 7.5 minutes.

The [MOTIS schema](https://github.com/motis-project/motis/blob/master/openapi.yaml) defines
`realTime` as availability of realtime information for the leg; it is not a per-stop accuracy
or freshness guarantee. The device cannot infer unreported delays or a feed's hidden age.

## Time axis and legend

- Left to right: 180 elapsed-minute slots, oldest to newest, with hourly guide lines and `3h` label.
- A minute uses its latest response. Retries do not create extra columns.
- Missed refreshes, failed requests, invalid device time and empty eligible sets leave gaps.
  A failed response also clears an earlier response in that same minute.
- Green: average under 1.5 minutes. Amber: 1.5 to under 4. Red: 4 minutes or more.
- Bar height: zero to 15 minutes (`15m` label). A white cap means above the visible scale;
  observations are not individually capped at 30 minutes. Only the storage maximum of
  6,553.4 minutes is saturated, well outside normal operating values.
- Red dots in the top track: at least one cancelled service in the same one-hour window.
- Grey dots in the second track: at least one non-cancelled service lacked comparable realtime
  information. This includes a wholly timetable-only snapshot with no coloured bar.
- Numeric bars occupy their own track below these markers; zero delay is a one-pixel green bar.

Elapsed time uses unsigned `millis()` arithmetic, so NTP corrections do not rearrange past
samples and the normal millis rollover is supported. The loop advances history during outages.
History lives in RAM. Since firmware 1.2.7 a copy is also kept in the chip's RTC memory, which
survives a software restart, a watchdog reset or a crash but not a power cut. It is written once
a second (magic word, format number, FNV-1a checksum) together with the wall-clock second at which
the newest slot began. After a restart, once the clock is set, `DelayGraph::resume()` re-anchors
it on the new `millis()` axis, so the restart and any time in setup become gaps. A copy that fails
the checks, lies in the future or is three hours old or more is dropped. Start over wipes it.

## Interpretation and limits

This is a history of the board's reported situation, not final departure punctuality or a
per-trip reliability score. The same upcoming train can appear in successive snapshots. Route
mix, service count and realtime coverage can change; missing observations are not interpolated.
The one-hour window follows returned departure time, so a very delayed train can enter or leave
it as its forecast changes. Cancellation markers cover only cancellations returned by the API.

A true final-departure reliability chart would need stable trip IDs, retained per-trip records
and confirmation after departure. That is a different measurement and is not claimed here.

## Why Rev1 changed

The old metric mixed cancellations with an invented 15-minute delay, included unknown realtime
as zero, clipped each train to 30 minutes, truncated seconds and drew an empty board as green.
Its 180 successful responses stretched across outages rather than representing three elapsed
hours. Rev1.1 removes those distortions and makes missing data visible.

The exact firmware implementation is exercised by [delay_graph_test.cpp](https://github.com/haldarsaurav/Headway_code/blob/main/tests/delay_graph_test.cpp) in the code repository.

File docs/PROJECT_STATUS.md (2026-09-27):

# Project status

## Closeout — firmware 1.2.8, 27 September 2026

**The project is wrapped up in software.** Firmware 1.2.8 is the final version: five looks
(Original default), readability pass from photos of the running board (1.2.2), scrolling on
every train page and a larger platform number (1.2.3), full bus names with their via part
when scrolling is on in every look (1.2.4), real umlauts in Original (1.2.5), the new name Headway (1.2.6), a delay graph that survives restarts (1.2.7), a 30-day temperature graph with each day's low and high (1.2.8), plus the 1.2.1 enclosure rotation,
Start over and button wording. Comments, CHANGELOG, READMEs, the feature guide and build notes
match the code. A final logic audit reviewed the drawing, scrolling, Split-Flap turning and
button paths; its only code change makes Original's scroll entries set their text offset
explicitly (no visible effect). `.gitignore` now also keeps the `_backup_before_*` folders and
any copy of `DeskSecrets.h` out of Git.

Checked on a PC: every screen of every look rendered from the real code under AddressSanitizer
and UBSan (normal data, stress data and 40 rounds of Split-Flap page changes, turns and
refreshes) with no errors; Original renders are pixel-identical to 1.2.1 apart from the version
number; 52 compile-time logic/graph assertions and 9 setup-page scenarios pass.

New phone photos and short video clips show a powered Headway prototype. They do not establish
that firmware 1.2.8 was flashed or that the current Rev9 / desk rev2 CAD has passed a fit check.

**Still needed for firmware 1.2.8 and the current CAD:**

1. Compile in the Arduino IDE (quit the IDE completely before opening the updated files).
   Expect roughly 76 % flash. Any compile error is new in 1.2.1–1.2.8.
2. Boot splash reads **Headway** and **v1.2.8** and is upright in the enclosure.
3. Serial after boot: `Theme <name>: fonts loaded, heap N` and the free heap after the first
   refresh (Bahnsteig and Papier load three more fonts than 1.2.1).
4. With scrolling on: train pages 2-4 scroll in Bahnsteig, Amber Matrix and Papier; Amber bus
   rows keep their umlaut dots while scrolling; Split-Flap names turn over every 3 s and the
   button stays responsive while they do.
5. With scrolling on, the P+R board shows "... ü. Gute Änger" scrolling in every look
   (Original too, with the real ü and Ä).
6. First train page: next-train block and the bigger platform number in all four font looks.
7. Setup page: Look card, Save, Start over. The setup Wi-Fi is now called **Headway-Setup**
   (the QR on the screen already knows the new name).
8. Delay graph through a restart: let the board run 10+ minutes, change the look and Save. After
   the restart the graph keeps its bars, with a short gap for the restart. Serial prints
   `Delay graph: restored, newest slot N s old`. Start over (or unplugging) empties it.
9. 30-day temperature graph: serial prints `Temperature history: 31 days, today low X high Y`; each bar floats from the day's low to its high, and the left numbers are the warmest high and coldest low. If every bar is only a thin mark, the lows did not arrive.

**Folder cleanup (27 Sep 2026):** backups, temporary files, the 1.2.0 previews and zip, and the
enclosure concepts and Rev1–Rev7 were removed. The enclosure folder keeps wall Rev9 (current) and
Rev8, desk rev2 (current) and rev1, and both photo-card sets; the release zip was rebuilt (now for 1.2.5).

## Rev1.2 audit — 26 September 2026

The five-look firmware and Rev7 enclosure files received a release audit. Small text contrast,
text fitting and countdown limits received a code audit. The local Rev1.2 ZIP
is generated with its source, font notices, CAD files and checksum manifest. The final
ESP32-C3 compile/link passed at 2,282,874 bytes flash and 52,452 bytes static RAM; 52
compile-time logic/graph assertions and five setup-page JavaScript scenarios pass. The screen previews
are illustrative and predate the last contrast pass. The display has not been flashed in this
audit, and the Rev7 enclosure has not been fit-tested. Check actual LCD legibility, button and
setup interactions, and printed clearances before calling the physical design verified.

## Rev1.1 closeout

**Software, documentation and repository packaging completed on 25 September 2026.**
Firmware remains **1.1.0**. The `rev1.1-final` tag adds the final documentation and permission
policy to the reviewed firmware revision; the earlier `rev1.1` tag is preserved unchanged.

## Delivered

- Reviewed firmware, including corrected delay snapshots and the prior reliability fixes.
- A dedicated [code repository](https://github.com/haldarsaurav/headway_code)
  for firmware, tests and build/release documentation.
- A [public showcase](https://github.com/haldarsaurav/headway) whose current
  branch contains documentation and images, with no firmware source or compiled firmware.
- The [complete feature guide](https://github.com/haldarsaurav/headway/blob/main/docs/FEATURE_GUIDE.md),
  covering screen fields, symbols, colours, graph legends, controls, examples and limitations.
- Two enlarged explanation diagrams, visually checked for clipping and legibility.
- Matching proprietary [licence](../LICENSE) and [permission guide](PERMISSIONS.md)
  in both repositories.
- A complete local Rev1.1 ZIP containing reviewed source, documentation and existing CAD
  snapshots, with a per-file SHA-256 manifest. Private settings and reference photos are excluded.

## Verification

The firmware release passed **52 compile-time logic/graph assertions**, **five actual embedded
setup JavaScript scenarios**, and ESP32-C3 compile/link/image generation. Finalization changes
only documentation, notices and illustration assets; the executable source matches the tested
Rev1.1 source. Documentation links, image files, repository separation and archive checksums
are checked as part of final packaging.

## Physical validation still open

The board was not flashed in this review. Physical display appearance, tiny marker legibility,
MODE and setup interactions on the device, Wi-Fi outage recovery over a long run, and enclosure
fit need an actual hardware session. Software/documentation completion does not certify those
physical results. The illustrations are not evidence of hardware testing.

## Publication and rights scope

The public repository's older commits may still contain the original firmware. They were not
rewritten. The new notices do not retrospectively revoke earlier valid grants or GitHub platform
rights, and cannot physically prevent copying. The owner nevertheless expressly
requires prior written permission for the protected reuse described in the licence.

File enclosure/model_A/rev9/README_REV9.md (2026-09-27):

# Headway enclosure - Rev9 (wall) = Rev8 + 4th screw, no slit, no photo columns, stronger ribs

<p align="center">Model A Rev9 isometric front shell CAD view</p>

[All five model views](../../README.md#model-a--wall-rev9) · [FreeCAD source](Headway_enclosure_rev9.FCStd) · [STEP export](Headway_enclosure_rev9.step)

Script: `../../freecad/enclosure_rev9.py`. Checked on the model only (not printed yet).
Print **shell + back plate** again (both changed). Key is the same as Rev6-Rev8.

## Changes vs Rev8
- **4th screw (corner boss):** new insert boss in the top-right inside corner (x 112.4, z 59.9), merged into the top and
  right walls. It grows from the front wall, but where it sits behind the photo card it steps back 0.3 mm behind the
  card with 45 deg slopes, so it never touches the card and prints face-down without support.
  Insert pressed in **from the back** (the plate side); screw **M2.5 x 6** countersunk through the back plate,
  3.0 mm thread in the insert. Now the back plate is screwed at 4 corners.
- **Top slit removed** (no more bridge in the top wall). The card now goes in from the inside before the back plate is
  closed and is fixed with a bit of tape/glue. Ledge, right rail and 0.6 mm pocket behind the window stay as locators.
- **Photo columns removed** from the back plate.
- **ESP32 ribs:** another 1 mm off the wall-side end (x 99.6-107.6; wire channel to the plate edge 8.5 mm, was 7.5),
  and stronger: 4.2 mm wide at the plate -> 2.4 mm at the tip (was 3.0 -> 1.8).
- Top vents moved 4 mm left to make room for the boss.

## Print (Bambu A1 mini, PLA, 0.2 mm, no supports)
| File | Orientation | Settings |
|---|---|---|
| `rev9_1_front_shell.stl` | front face down | 3 walls (4 is better around the insert posts), 15 % infill |
| `rev9_2_back_plate.stl` | flat back down | same |
| `rev9_3_boot_key.stl` | face down | same key as Rev6-Rev8 - reuse yours if you have one |
| `rev9_0_optional_fit_test.stl` | face down | front part only, to check the display window before the full shell |

## Hardware (from Saurav's kits)
- 4 x **M2.5 x 3 x 3.5** knurled brass inserts (TexSync kit): 3 in the display posts + 1 in the corner boss
- 3 x **M2.5 x 12** countersunk Phillips screws (display holes) + 1 x **M2.5 x 6** countersunk (corner boss) (AIMUNOK kit)

## Assembly
1. **Inserts:** soldering iron at ~210-220 C, press slowly and straight until flush.
   - The 3 display-post inserts go in from the front side of the posts (bottom-left, top-left and bottom-right corners
     of the display area). There is 1.5 mm of front wall under each, so the front face stays clean.
   - The corner-boss insert goes in from the back (the open side of the shell), flush with the boss top.
2. Key into its hole, Super Mini into its band.
3. **Card:** put it behind the photo window from inside (resting on the ledge, against the right rail) and fix it with
   a bit of tape or glue.
4. Display glass-down onto the 3 insert posts, its holes over the inserts.
5. Back plate on (it sits on the step all round). Screw the 3 M2.5 x 12 in from the back, through the plate, the
   spacer and the display hole into the insert. Before the final turn, nudge the display so the picture is centred in
   the window (the screws have ~0.3 mm play in the display holes), then tighten gently - snug is enough.
   Then the M2.5 x 6 into the top-right corner boss.
6. To open: undo the 4 screws and lift the plate.

## What each screw does
Display screws: back plate countersink -> solid spacer (presses the display board) -> display mounting hole -> brass
insert in the front shell post, so the same 3 screws close the case AND clamp the display. The 4th (corner) screw only
holds the plate's top-right corner.

## Checks (script)
All overlaps 0; corner screw only meets its insert hole; boss vs card 0; key, RESET, display screws unchanged.

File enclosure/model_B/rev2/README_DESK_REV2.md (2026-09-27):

# Model B · desk case, rev2

[Back to both models](../../README.md) · [FreeCAD model](Headway_desk_rev2.FCStd) · [STEP export](Headway_desk_rev2.step)

<p align="center">Model B rev2 isometric shell view</p>

This version sits in a separate 15° stand with USB-C accessible from the right. It inherits the Rev9 wall case's fourth insert boss, closed top edge and stronger ESP32 ribs. The picture card goes in from inside before the back plate is fitted; there is no top insertion slit in rev2. The stand is unchanged from rev1 and can be reused.

## Parts to print

- `desk_rev2_0_optional_fit_test.stl` — a short front-section test for the display window.
- `desk_rev2_1_front_shell.stl` — front face down; 0.2 mm layer, 3 walls (4 around insert posts), 15% infill.
- `desk_rev2_2_back_plate.stl` — back face down; the same wall and infill settings.
- `desk_rev2_3_boot_key.stl` — face down; the key is reusable from earlier versions.
- `desk_rev2_4_stand.stl` — flat bottom down; 3 walls, 25% infill.

These settings are from the model notes for a Bambu A1 mini and PLA, without supports. A short fit test is sensible before the full shell.

## Hardware and assembly

Use **four M2.5 × 3 × 3.5 mm knurled brass heat-set inserts**, **three M2.5 × 12 mm countersunk screws** for the display posts and **one M2.5 × 6 mm countersunk screw** for the corner boss. Four small adhesive feet under the stand are optional.

1. Press the three display-post inserts in from the front side of the posts and the corner-boss insert in from the back. The model notes suggest a soldering iron around 210–220 °C; press each slowly and straight until flush.
2. Put the BOOT key in its hole. Fit the Super Mini in the right-side band, with USB-C through the right slot, antenna end against the stop and BOOT edge up.
3. Put the picture card behind its window from inside. Rest it on the ledge, align it against the rail and secure with a little tape or glue.
4. Set the display glass-down on the three posts. Fit the back plate and insert the three long screws through its spacers and display holes into the inserts. Adjust the picture in the window before the final gentle turn. Fit the short fourth screw at the corner boss.
5. Lower the case into the stand with the screen toward the low front lip. Plug USB-C in from the right; the case lifts out without removing the stand.

The stand model is 128.5 × 60 × 10 mm and gives a 15° lean. It covers 3.2 mm of the front face and 7.2 mm of the back; the script-level clearance check keeps the screen, key, reset access and USB opening clear. These are CAD checks only. The current parts have not had a complete physical fit and heat check.

<p align="center">Separate Model B desk stand CAD view<br><sub>Separate stand, rendered from the FreeCAD STL export.</sub></p>

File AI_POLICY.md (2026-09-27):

# AI and automated-use policy

**Prior written permission from Saurav Haldar (@haldarsaurav) is required.**
This is a proprietary project. Public visibility is not an invitation to reuse it.

Please do not scrape, crawl, bulk download or collect my original writing, project plan,
build notes, diagrams, photos, video clips, CAD, screen designs or code for AI training,
retrieval, automated summaries intended for replication, or a copy of this project.
The documented plan and the way these parts are expressed and combined are part of what
I am asking people to respect. Ask me before reusing that material, even if you intend
to rewrite it or use it only as a starting point.

Without that permission, do not use protected project material:

- to train, fine-tune, distil, evaluate or improve AI/ML models, or to create datasets;
- in prompts, contexts, embeddings, retrieval stores or agent inputs for reuse or replication;
- as inspiration, a template, reference or specification to copy or reconstruct the project's
  implementation, documented logic, original screen design or expressive feature arrangement;
- to produce a rewritten, translated or non-verbatim version derived from that material.

The policy applies to human users and organisations operating AI systems, as well as model
providers and automated tools. Credit or noncommercial intent does not replace permission.
The owner's explicit instruction to a collaborator or tool authorizes only the requested work.

[Ask the owner for permission](https://github.com/haldarsaurav/headway/issues)
and wait for an explicit written grant describing the permitted use. Include which material,
version, intended output, tools/models and distribution you propose. If issues are unavailable,
use a contact method published on [the owner's profile](https://github.com/haldarsaurav).

The full [LICENSE](LICENSE), including its third-party, platform and applicable-law provisions,
controls. This policy states my permission terms; it is not a technical crawler blocker or a
claim of exclusive legal rights over abstract ideas, algorithms or general features.

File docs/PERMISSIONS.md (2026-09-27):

# Permission and reuse

**All rights reserved. Ask first, and receive written permission before reuse.**

The owner wants the project to be viewable as a showcase, without granting others permission
to copy its work or recreate its implementation or presentation. Both repositories
carry the same [full proprietary licence](../LICENSE).

## Examples

| Proposed action | Owner's permission policy |
| --- | --- |
| Read the public feature guide on GitHub | Viewing through the service is covered by the applicable platform terms |
| Flash the firmware onto your own ESP32 | Ask for written permission first |
| Copy screen artwork or documentation into another project | Ask first |
| Sell a device incorporating the project | Ask first; disclose commercial use |
| Recreate the implementation or presentation from files or screenshots | Ask first, including when the new work uses different source text |
| Scrape, bulk download or build a dataset from the project | Ask first |
| Star the project, cite its URL or request permission | None of these actions grants reuse permission |

Requests should identify the requester, material/version, intended use, commercial status
and planned distribution. Send the request through the
[public repository's issues](https://github.com/haldarsaurav/headway/issues)
or a contact method published on [the owner's profile](https://github.com/haldarsaurav).
Silence is not consent. Only the owner can grant project permission.

## What a notice can and cannot do

A restrictive notice expresses the owner's terms; it does not physically prevent downloads
or guarantee that third parties obey. GitHub's public-repository terms include service-specific
viewing and forking rights. See [GitHub's licensing guidance](https://docs.github.com/en/repositories/managing-your-repositorys-settings-and-features/customizing-your-repository/licensing-a-repository).

Copyright does not create ownership of abstract ideas, methods or algorithms simply because
they are described in a project. The licence therefore distinguishes protected project material
from generic features and independently created work. See the
[U.S. Copyright Office's software guidance](https://www.copyright.gov/register/tx-programs.html).
Legal protection and exceptions depend on applicable law; the notice preserves those limits.

Text/data-mining reservations can have jurisdiction-specific requirements. For example,
[German Copyright Act section 44b](https://www.gesetze-im-internet.de/urhg/__44b.html) specifies
machine-readable reservation for online works. These repository notices do not claim that a
particular crawler must recognize them or that every technical/formal requirement is satisfied.
Third-party libraries, data and trademarks keep their own terms.

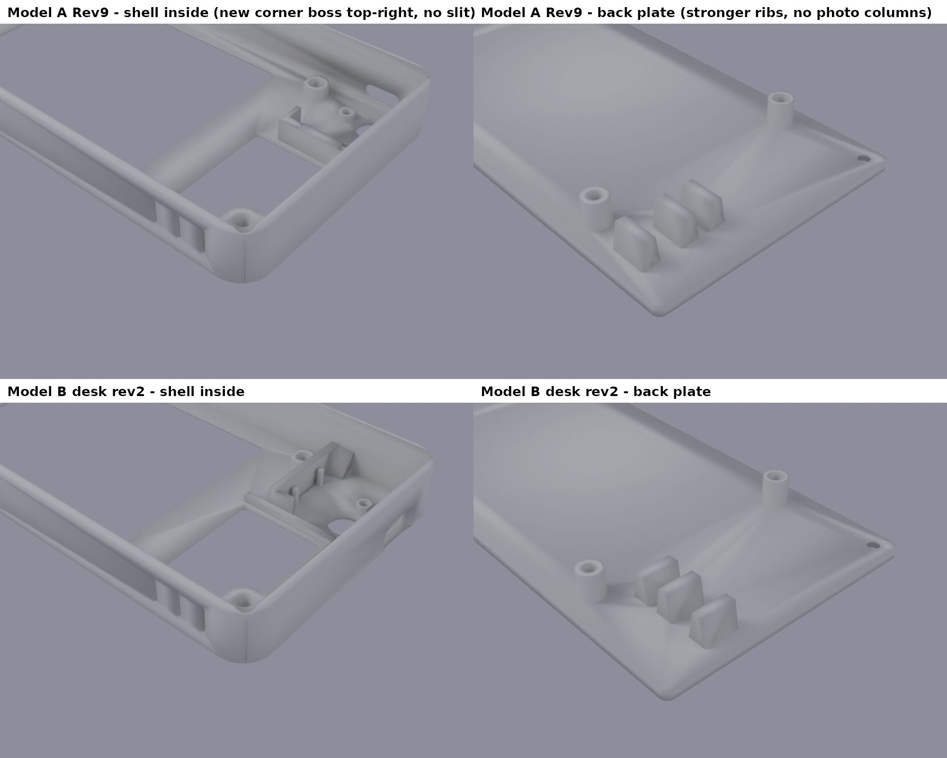
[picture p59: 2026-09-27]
enclosure/model_A/rev9/images/rev9_desk2_overview.png

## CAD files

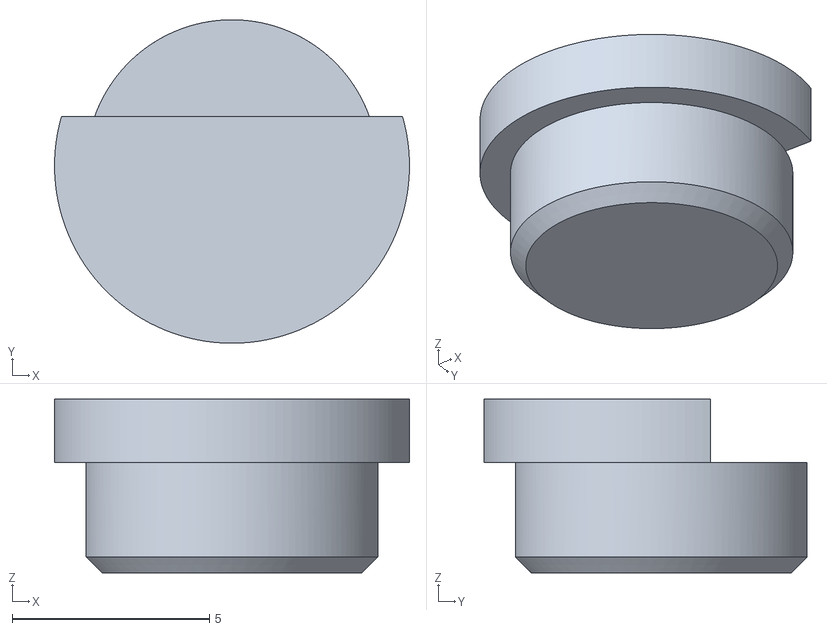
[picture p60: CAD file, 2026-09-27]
enclosure/model_A/rev9/rev9_3_boot_key.stl
9.00 x 8.20 x 4.40

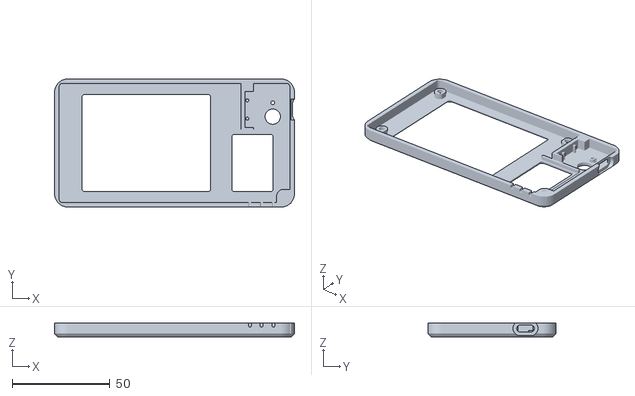
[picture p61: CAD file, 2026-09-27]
enclosure/model_B/rev2/desk_rev2_0_optional_fit_test.stl
122.5 x 65.5 x 7.00

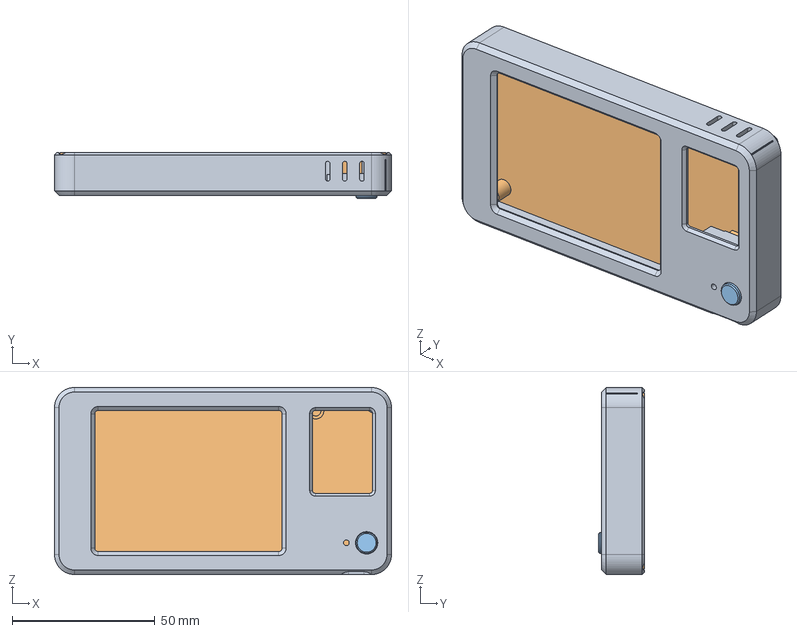
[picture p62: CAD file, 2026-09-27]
enclosure/model_A/rev9/Headway_enclosure_rev9.step
118.0 x 16.0 x 65.5 mm

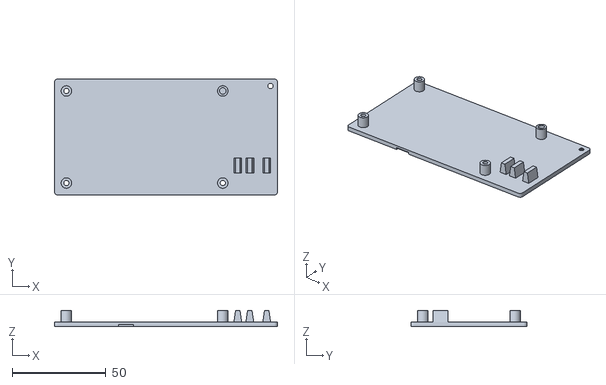
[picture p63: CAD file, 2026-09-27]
enclosure/model_B/rev2/desk_rev2_2_back_plate.stl
118.8 x 61.8 x 8.60

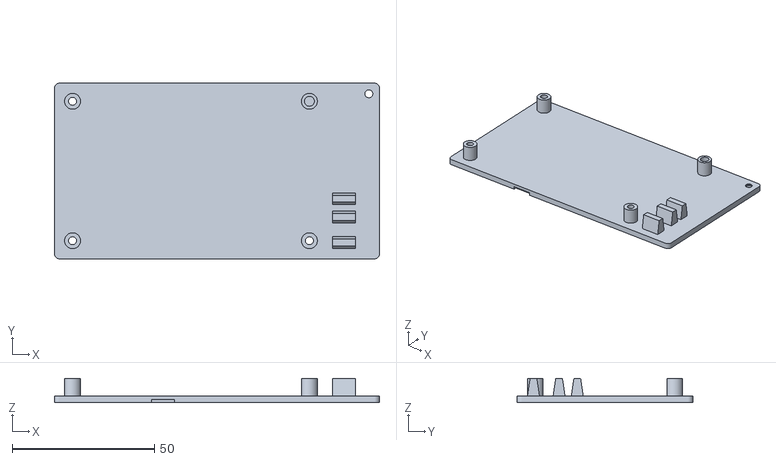
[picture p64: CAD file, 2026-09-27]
enclosure/model_A/rev9/rev9_2_back_plate.stl
114.3 x 61.8 x 8.60

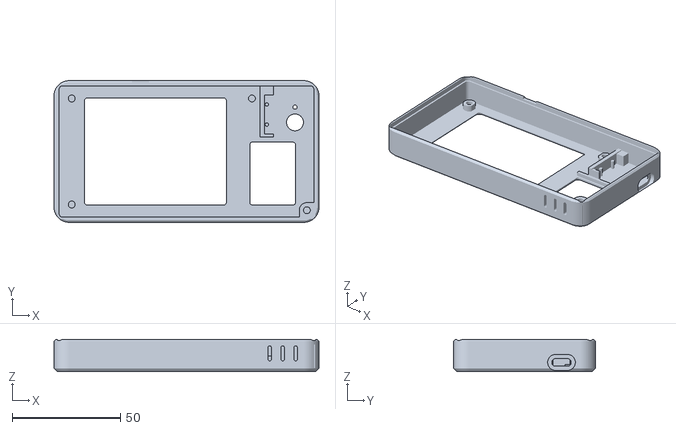
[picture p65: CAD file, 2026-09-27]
enclosure/model_B/rev2/desk_rev2_1_front_shell.stl
122.5 x 65.5 x 15.0

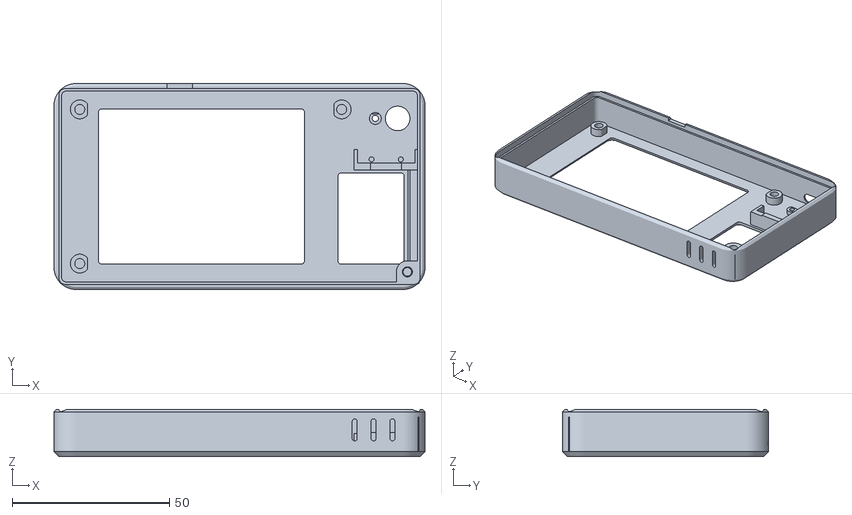
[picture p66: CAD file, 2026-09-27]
enclosure/model_A/rev9/rev9_1_front_shell.stl
118.0 x 65.5 x 15.0

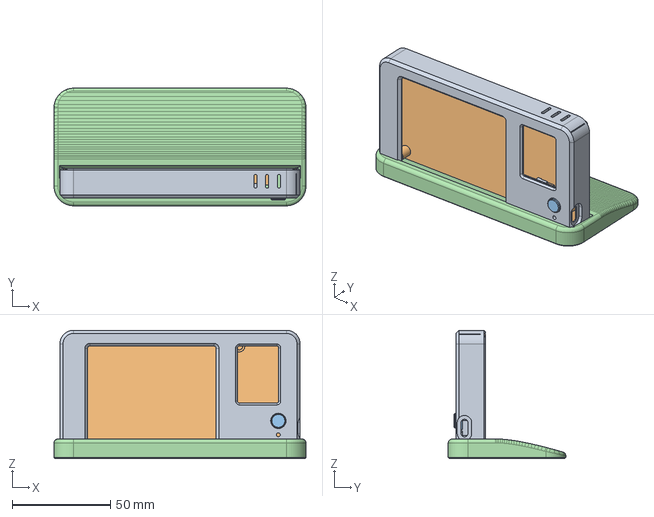
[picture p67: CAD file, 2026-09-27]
enclosure/model_B/rev2/Headway_desk_rev2.step
128.5 x 60.0 x 65.5 mm

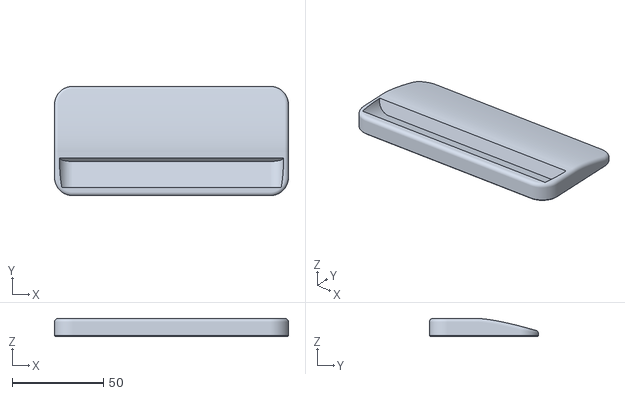
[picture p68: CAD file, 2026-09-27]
enclosure/model_B/rev2/desk_rev2_4_stand.stl
128.5 x 60.0 x 10.0

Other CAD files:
enclosure/model_B/rev2/desk_rev2_3_boot_key.stl
enclosure/model_A/rev9/rev9_0_optional_fit_test.stl
enclosure/model_A/rev9/Headway_enclosure_rev9.FCStd
enclosure/model_B/rev2/Headway_desk_rev2.FCStd

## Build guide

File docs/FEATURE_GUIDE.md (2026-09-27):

# Complete screen, icon and feature guide

**Feature meanings from Rev1.1, retained in Rev1.2 · firmware 1.2.8**

This guide uses the **Original** look to explain the data fields, symbols, colours and controls.
Rev1.2 also offers Bahnsteig, Amber Matrix, Papier and Split-Flap; their layouts and palettes
vary, while the data and controls described here remain the same. See the [switchable gallery](index.html#screens) for every look and page.
All examples are invented to
explain the display; they are not live departures or a forecast. The enlarged legend diagrams
are explanatory drawings. The screen renders below use the 1.2.6 drawing code; 1.2.7 changes the boot version and
restart handling, while 1.2.8 adds the low-to-high temperature history graph.

[Back to the project](../README.md) · [Permission and reuse](PERMISSIONS.md)

## Find a feature

- [Pages and navigation](#pages-and-navigation)
- [Train columns, badges and examples](#train-pages)
- [Bus pages and bay markers](#bus-pages)
- [Every weather symbol](#weather-symbols)
- [Current-weather numbers and colours](#weather-now)
- [The next-twelve-hours chart](#next-twelve-hours)
- [Three-day rows, rain timing and moon phase](#next-three-days)
- [The three-hour delay graph](#train-delay-history)
- [The temperature-history graph](#temperature-history)
- [Health dot and messages](#data-health-and-messages)
- [Boot, buttons, setup and QR codes](#boot-controls-and-setup)
- [Settings, examples and troubleshooting](#settings-and-examples)
- [Data limits and release status](#data-limits-and-release-status)

## Pages and navigation

The page sequence is **trains → Bahnhof Stadtbus → P+R-Platz → weather now → next three days**,
then back to trains. Trains occupy one to four pages of six entries, depending on the returned
services. There are therefore five to eight screens in total. Both bus stops always have their
own page, with up to ten departures each.

Tap the button to move forward. Automatic page changing and long-name scrolling are independent
options and both default to off. With automatic changing enabled, a manual tap also restarts
the page's dwell time. When the train-page count changes, the selected bus/weather page is kept
as the same kind of page rather than unexpectedly jumping to another feed.

| Visual treatment | Meaning and reason |
| --- | --- |
| Navy train page with olive-yellow column band | A station-board style; the band separates labels from departures |
| Alternating row shading and thin rules | Help the eye follow one service across its columns; not another status |
| Black bus page with amber route/destination text | A stop-board style; amber text is normal, not a delay warning |
| Weather background | Time-of-day cue, explained under weather colours below |
| Rows appearing in a short cascade on page changes | Makes the page transition visible without a long animation |
| A long name moving sideways | Optional text scrolling, not movement of the actual vehicle |
| A name ending in `..` | The name was shortened to fit; it is not a special stop name |
| Slightly shorter Ä, Ö, Ü | Capital umlauts are drawn a little lower so the dots fit the line height, as on LED signs |

### What the other looks add (firmware 1.2.2 and later)

Bahnsteig, Amber Matrix, Papier and Split-Flap show the same data with a few extra cues. Real
umlauts (ä, ö, ü, ß) are drawn in every look, Original included (since 1.2.5).

| Visual treatment | Meaning and reason |
| --- | --- |
| Large block at the top of the first train page | The next departure: countdown in minutes, line, time (struck planned time and `+N` when late), destination, and the platform on its own sign (`GLEIS` / `GL`); the five departures after it follow as rows |
| Destination sliding sideways (any train or bus page) | The name is longer than its space and scrolling is on; with scrolling off it ends in `…` |
| Split-Flap: a name changing to its second half every 3 s | The same long name shown in parts, like a real flap board; a via part (`Ü. …`) always starts a new part |
| Split-Flap: a few flaps briefly flipping | New data changed those characters (for example the countdown); flaps that did not change stay still |
| Split-Flap weather: stack of small flaps under each hour | Lit up to that hour's temperature relative to the next 12 hours (one flap coldest, five warmest), in its temperature colour |
| Split-Flap weather: narrow blue stack beside it | Chance of rain in that hour, one flap per 20 % |

## Train pages

Train page: illustrative layout

| Item | What it means | Why it is there / example |
| --- | --- | --- |
| `Freising` at top left | The configured rail station | Confirms which station the board covers; changing weather town does not change it |
| Top-right `HH:MM` | The device's current local clock | A reference for departure times; it may be blank before time synchronisation |
| `Line` badge | Train route/service label | `RE22` identifies the service, not its platform |
| White badge, red border and text | Styling used for non-S-Bahn train labels | Separates the service category visually; red here does not mean a delay |
| Blue rounded badge with white text | S-Bahn-style label | For a short label such as `S1`; styling is based on the returned line name |
| `To` | Destination/headsign | Helps identify the right direction |
| `Pl.` | Platform from the feed | `3` means the reported departure platform; `-` means no useful value was supplied |
| `plan` | Original scheduled time, shown when a positive whole-minute delay changes the displayed time | A small struck-through `09:55` explains what changed |
| Small `+5` below the planned time | Reported delay in whole minutes | Five minutes later than scheduled; seconds are truncated for this row label |
| `time` | Returned departure time, using the scheduled time if no usable revised time exists | This is the displayed departure estimate, not confirmation that the train departed |
| Green departure time / countdown | No positive whole-minute delay in the returned data | May still be timetable-only, early, or less than one minute late; green is not proof of live punctuality |
| Red departure time / countdown | A positive reported delay, or cancellation | Gives changes more visual prominence |
| `min` | Rounded minutes remaining, shown only from 0 to 60 | `3` is approximately three minutes; `0` means due around now, not a confirmed departure |
| Empty `min` field | Outside the displayed countdown range or no valid clock | Read the adjacent clock time instead; blank is not cancellation |
| Red struck-through destination and `X` | Service cancelled according to the feed | Cancellation overrides any clock time still visible on the train row |
| `1/3` in the footer | Train page one of three | It counts train pages only; it is not a delay or health score |
| Footer dot and small graph | Feed health and delay-history snapshot | They answer different questions; see their separate legends below |

### Train examples

At a device clock of **09:57**, a train scheduled for **09:55** but now expected at **10:00**
shows ~~09:55~~, **+5**, a red **10:00**, and approximately **3** minutes remaining.

A service returned for **10:00** with no positive reported delay can show **10:00 / 3** in green.
That appearance alone does not tell you whether the provider supplied realtime data. The delay
graph uses a stricter realtime requirement and excludes unknown delays from its mean.

A cancelled service shows a red struck-through destination and **X**. Do not interpret its
remaining time as a valid departure promise. An entry more than about one minute in the past
is removed during the minute update, including when refreshes are failing.

Cancelled train names stay still so their strike-through remains readable. Other long names
can scroll if enabled.

## Bus pages

| Bahnhof Stadtbus | P+R-Platz |
| --- | --- |
| Town bus page | P+R page |

The white header names the stop and shows the local clock. The Bahnhof Stadtbus page keeps
city-bus routes, filtering regional/express coach routes. P+R-Platz shows the other configured
stop. Each page has its own health state; there is no shared bus-delay graph.

| Item | Meaning, purpose and example |
| --- | --- |
| Amber route number, e.g. `640` | Which bus to look for; ordinary bus text is amber |
| Amber destination | Where the service is headed; bracketed bay notes and long via-details may be shortened for legibility |
| Small grey bay number | Reported boarding bay; shown as a column only when it distinguishes the visible services |
| Small grey `N`, `S`, `E` or `W` | Approximate side of the stop inferred from available stop coordinates when no real platform label exists; not the bus's travel direction |
| No bay column | No useful variation among available bay labels, or insufficient information; more width is then given to destinations |
| Struck-through small clock time | Scheduled time of a delayed bus, placed left of its revised time |
| Green or red main clock time | Same returned-time convention as the train page; green is not a guarantee of realtime data |
| Rightmost number | Rounded minutes to departure, 0–60; absent outside that range |
| Red destination strike-through and `X` | Cancellation; the bus row suppresses the normal time/countdown block |

**Example:** at **10:27**, a bus scheduled for **10:27** but expected at **10:30** shows the
struck-through planned time, red **10:30**, and **3**. Unlike the taller train row, the bus row
does not add a separate `+3` line. A grey bay **4** means board at the reported bay 4; an inferred
**N** is only a rough side-of-stop aid and should be checked against actual signage.

## Weather symbols

Enlarged weather icons and health-dot legend

The condition pictogram is a compact category symbol, not a live camera image. The current
page selects its day/night variation using the day's sunrise and sunset. Outlook rows use
daytime condition symbols because they summarize a whole day.

| Shape | Meaning | Why / example |
| --- | --- | --- |
| Yellow sun with rays | Clear or mainly clear, daytime | A quick sky-condition cue |
| Pale crescent without a cloud | Clear/mainly clear at night | Replaces the sun after sunset or before sunrise; this crescent is not the calculated moon phase |
| Sun partly behind a pale cloud | Partly cloudy or overcast | One cloud category keeps the tiny icon simple; an overcast forecast can still use this symbol |
| Crescent partly behind a cloud | The cloud category at night | Same weather grouping with a night cue |
| Cloud plus horizontal grey lines | Fog, including depositing rime fog | Horizontal layers distinguish fog from falling precipitation |
| Cloud plus blue diagonal strokes | Drizzle, rain, freezing rain/drizzle or rain showers | Blue falling strokes signal the precipitation category; intensity/freezing details are not individually drawn |
| Cloud plus pale dots below | Snow, snow grains or snow showers | Dots differentiate frozen precipitation from the rain strokes |
| Cloud plus yellow lightning bolt | Thunderstorm category | It describes weather; it is not an electrical or battery fault indicator |
| No condition pictogram | Missing/unrecognised condition code | An absent icon should not be interpreted as clear weather |

The text description is deliberately brief: `Clear`, `Cloudy`, `Fog`, `Rain`, `Snow`, `Showers`
or `Thunderstorm`. The current implementation groups condition codes 1–3 under the text
`Cloudy`, although code 1 uses the mainly-clear sun/moon icon. The symbol and short text are
therefore not a detailed cloud-percentage report.

The category groups follow the provider's [weather-code reference](https://open-meteo.com/en/docs).
The guide describes the project's simplified rendering rather than claiming a distinct symbol
for every possible weather code.

## Weather now

Current weather: illustrative screen

| Item | Meaning | Why / example |
| --- | --- | --- |
| Town name in header | Weather location currently in use | Confirms which town the forecast lookup selected |
| Header clock | Current local device time | Different from the last-refresh time in the footer |
| Large number plus yellow degree ring and `C` | Current air temperature in Celsius | `18.4 °C`; the small ring is the degree sign, not another status dot |
| `feels 17C` | Current apparent temperature | A compact comparison with air temperature; it incorporates more than air temperature alone |
| `high / low` | Today's forecast maximum and minimum | `22 / 11` is the daily range in Celsius, not two current sensor readings |
| Blue percentage | Today's maximum hourly precipitation probability | `70%` is a likelihood statistic, not “70% of the day is wet” |
| Small `3mm 12-16h` below rain | Daily precipitation amount and the first-to-last qualifying wet-hour window | Amount is rounded to whole millimetres here; the time span may contain dry gaps |
| `at 15h` | A single qualifying wet hour | Approximately 15:00–16:00 in the model's hourly bins |
| `rain` without a time window | No qualifying wet-hour window was identified | It does not establish that precipitation is impossible |
| `humidity` percentage | Current relative humidity | A separate measurement from precipitation probability |
| Wind number with `km/h` | Current wind speed | `18` means approximately 18 kilometres per hour |
| Compass letters `N NE E SE S SW W NW` | Direction the wind comes **from** | `km/h NW` means wind from the northwest, not toward it |
| Sun above a horizon with upward arrow | Sunrise time | The upward cue distinguishes morning from evening |
| Sun above a horizon with downward arrow | Sunset time | The downward cue identifies the end of daylight |
| Faint bottom-right clock | Time of the last successful weather fetch on the device | It is not the forecast model's issue time, and does not describe temperature-history freshness |

### Temperature and background colours

The large temperature is blue at **0 °C or below**, pale blue above 0 through **10 °C**, white
above 10 through **20 °C**, warm cream above 20 through **27 °C**, and orange above **27 °C**.
These are visual temperature cues, not official weather warnings.

The weather background is lighter blue in daytime, plum within approximately **40 minutes
before or after sunrise/sunset**, and deep navy at night outside those transition windows.
It falls back to the daytime colour when time/sun information is unavailable. The background
can be plum while a sun or crescent is shown because twilight colouring and the day/night
condition symbol use different boundaries. Colours update when the page redraws.

Weather background examples

## Next twelve hours

The strip at the bottom of the current-weather page combines two measurements with different
scales. Normally it starts with the current hour and continues for up to twelve returned hours.
It needs at least two usable temperature points to appear.

| Mark | Meaning and reason |
| --- | --- |
| Blue vertical bars | Hourly precipitation probability; taller means more likely, not more millimetres |
| Orange line and small orange dots | Hourly temperature trend; dots identify the sampled hourly points |
| Warm/cool numeric `C` labels on the right | Upper and lower limits of the temperature plot; read these before comparing slopes across days |
| Yellow left edge, tinted first column and yellow first hour label | Identifies the strip's starting/current-hour position under normal complete data |
| Hour labels such as `09`, `12`, `15` | Local hour, printed every third point to keep the strip readable; the sequence may cross midnight |

**Example:** a tall blue bar at `15` with a falling orange line suggests a higher precipitation
probability around 15:00 while the temperature forecast is falling. The line is automatically
scaled with at least a 3 °C range; a steep-looking line is not automatically a large change.
If the provider omits hours, the compact strip can skip unusable points and its first column
is only the first retained hour, so do not assume perfect hourly coverage from position alone.

## Next three days

Three-day outlook: illustrative screen

There is one row for each of the next three days **after today**. Each row has three bands:
conditions/temperatures, rain timing, then sun/daylight/wind/moon information.

| Item | Meaning and reason |
| --- | --- |
| Yellow `Mon`, `Tue`, etc. and small `DD.MM.` | Day and date; the date makes the correct day identifiable at a glance |
| Small condition icon | Day's summary condition, using the weather-symbol groups above |
| Warm-coloured `21C` and cool `/10C` | Daily high and low; the slash pairs the two values |
| Small `feels 19` | Daily maximum apparent temperature, shown only when it differs from the high by at least 1 °C; it need not occur at the same hour as the actual high |
| `UV 4` | Rounded daily maximum UV index, not degrees or a percentage |
| UV green / yellow / orange / red | Display bands 0–2 / 3–5 / 6–7 / 8 and above; red combines the higher categories |
| Dark horizontal trough with blue stretches | Twenty-four-hour precipitation timing bar, detailed below |
| `40% 1.2mm` beside the bar | Daily maximum precipitation probability and daily precipitation total |
| `dry` or `20% dry` | No hourly bin crossed the project's wet-hour threshold; a nonzero probability can still be shown |
| Small yellow sun with short line above it | Sunrise, a compact version of the larger sunrise symbol |
| Small muted sun with a line underneath | Sunset, a compact version of the larger sunset symbol |
| `12h05` | Time from sunrise to sunset: 12 hours 5 minutes, not hours of unclouded sunshine |
| `+2m` or `-3m` beside day length | Change from the preceding day's daylight duration; omitted when zero |
| `18 km/h` | Daily maximum wind speed; this compact row intentionally has no direction arrow |
| Small shaded moon disc at the far right | Approximate lunar phase for that day, detailed below |

### Reading the rain-timing bar

Left is **00:00**, right is **24:00**. Small ticks underneath mark **06:00**, **12:00** and
**18:00**. A blue segment is an hourly bin with forecast precipitation of at least **0.1 mm**
**or** probability of at least **60%**. The dark trough means the threshold was not met; it is
not proof of zero risk or complete input data. Precipitation can include snow-water equivalent.

**Example:** blue around **07:00–09:00** and again **17:00–18:00**, with darkness in between,
shows two qualifying periods. The one-line current-weather label may summarize that as
`7-18h`; this bar preserves the intervening gap. It is a timing display, not a probability-height
chart: the probability bars are on the other weather page.

### Reading the moon disc

A mostly dark disc is near new moon; a thin bright portion is a crescent; half-bright is a
quarter phase; a mostly bright disc is gibbous; a bright full disc is near full moon. The
right-hand bright side depicts waxing and the left-hand bright side depicts waning in this
display's convention. The rim keeps a dark disc visible.

This phase is calculated approximately from the date using a fixed lunar cycle. It is not
measured by the board, not a moonrise time, and not the generic night crescent on the current
weather page. Treat it as a visual calendar cue, not an astronomical ephemeris.

## Train delay history

Rev1.1 delay graph with enlarged illustrative data

This footer is shared across all train pages. Each observation concerns fetched non-cancelled
trains due from now through the next hour with comparable realtime and scheduled times.
Their positive reported delays are averaged; early running contributes zero lateness. The
same upcoming train can appear in successive observations. This is a **board-snapshot history**,
not final departure performance for unique trains.

| Mark | Meaning and reason |
| --- | --- |
| `3h` and 180 columns | Three hours of elapsed-minute slots, oldest left and newest right |
| Faint vertical guides | Hour divisions; they remain even where samples are missing |
| Green bar | Average reported delay below 1.5 minutes |
| Amber bar | Average from 1.5 to under 4 minutes |
| Red bar | Average 4 minutes or more |
| A one-pixel green baseline bar | A usable sample reporting zero lateness; different from a missing sample |
| `15m` | Full visible bar-height scale, 15 minutes |
| White cap on a tall bar | Average exceeds the visible 15-minute scale; it has not been treated as merely 15 minutes in the calculation |
| Red dots in the separate top track | At least one returned cancellation in the same next-hour window |
| Grey dots in the track below | At least one non-cancelled candidate lacked usable realtime comparison |
| Blank interval | Missing/failed refresh, no eligible observation or invalid clock; not a zero-delay claim |

One cancellation plus one reported on-time train gives a cancellation marker and zero delay,
not an invented average of 7.5 minutes. A timetable-only board has no numeric delay bar and
can have the grey coverage marker. Two reported delays of 90 and 180 seconds average to
**2.3 minutes** after rounding once to a tenth. An early train does not subtract from another's delay.

Multiple responses within one minute replace that minute's reading. Outages retain gaps;
old samples age out even if no new response arrives. Since firmware 1.2.7 the history survives
a restart - Save on the setup page (for example a new look), a watchdog or a crash - and the
minutes the board spent restarting or in setup show as gaps. Unplugging the board clears it,
and so does **Start over**. The fetched board is capped at 24 trains,
so it is not a complete census of station traffic or a measure of all cancellations.

## Temperature history

The small graph at the bottom of the three-day page is a different measurement: up to **30
previous days plus today, each with its daily low and daily high**, supplied by the weather
service (firmware 1.2.8 and later; before, only the highs). These are provider weather/model
values, not readings from a temperature sensor in this desk device. Today's low and high are
still forecast values.

| Mark | Meaning and reason |
| --- | --- |
| One bar per day | Oldest left, today on the right; shorter available histories leave unused space |
| Bottom and top of a bar | That day's low and high, scaled from the coldest low to the warmest high in the window; not the fixed delay-graph scale |
| Tall or short bar | A large or small day-night swing |
| Blue through cyan/green to yellow/orange/red | The temperature of each pixel row, so a bar runs cool at its foot and warm at its top; smoothly blended rather than a warning level |
| Look-specific texture | Theme shading or LED rows; visual texture, not extra data |
| Warm upper and cool lower numbers at left | The warmest high and coldest low within the displayed window |
| Short 2 px mark instead of a bar | The service gave that day's high but no low |
| Faint week marks | One, two, three and four weeks back from today |
| Cap on the final bar | Identifies today; unlike the train graph, it does not mean scale overflow |
| Missing bar | No usable daily high for that position |

The colour reference runs from blue at roughly **−10/0 °C**, through cyan near **8 °C**, green
near **15 °C**, yellow near **20 °C**, orange near **25 °C**, and red near **32 °C**. This history
is fetched at boot and refreshed on roughly a six-hour schedule. The weather footer's refresh
time and health dot describe the main forecast feed, not independent freshness of this history.

## Data health and messages

The small footer dot reports the health of **the feed used by the current page**. A healthy
weather response cannot make a failed train page green. A cancellation is a transport event,
not necessarily an unhealthy API, so a green dot and a cancelled train can correctly coexist.

| Appearance | Meaning | Why / example |
| --- | --- | --- |
| Grey dot | No first fetch attempt completed yet, while Wi-Fi is connected | Startup is different from an established good reading |
| Green with an expanding faint ripple | Latest fetch succeeded and the feed is still fresh | A small heartbeat shows that the display loop is active |
| Amber/yellow | Latest fetch failed, but a previous good reading is still recent | A temporary retry can usefully retain the last response |
| Blinking red | Wi-Fi disconnected, no usable data after an attempt, or last good data at least 3.5 minutes old | Makes stale/unavailable data visible; do not treat retained entries as confirmed current information |
| Dimmer dot of the same colour | Network work is in progress | Busy does not replace or conceal an existing failure state; the healthy ripple pauses |
| Faint red outline during a blink's dark half | Position of the red indicator | Prevents the missing-looking dot from being mistaken for no indicator |

| Text | Meaning |
| --- | --- |
| `Loading...` | First result is still awaited |
| `No departures` | A recent successful response left no displayed departures, including after expiry |
| `Data unavailable` | The departure feed failed or is stale |
| `No weather data` / `No forecast` | A suitable weather/current or outlook result is unavailable |
| `Live` | All principal feeds in the latest refresh cycle succeeded; not a guarantee that every train has realtime data |
| `Partly offline` | Some feeds succeeded and others failed |
| `Data source offline` | No principal feed in that cycle succeeded |
| Empty field or `-` | A value may be missing or intentionally omitted to avoid repetition |

Refreshes are attempted around a one-minute cadence, with network delays affecting actual
completion. Countdown rows still update each minute during an outage. Persistent failures
trigger recovery: Wi-Fi reconnect attempts, and eventually a restart after prolonged Wi-Fi or
data loss. No new departure information can be created while offline.

## Boot, controls and setup

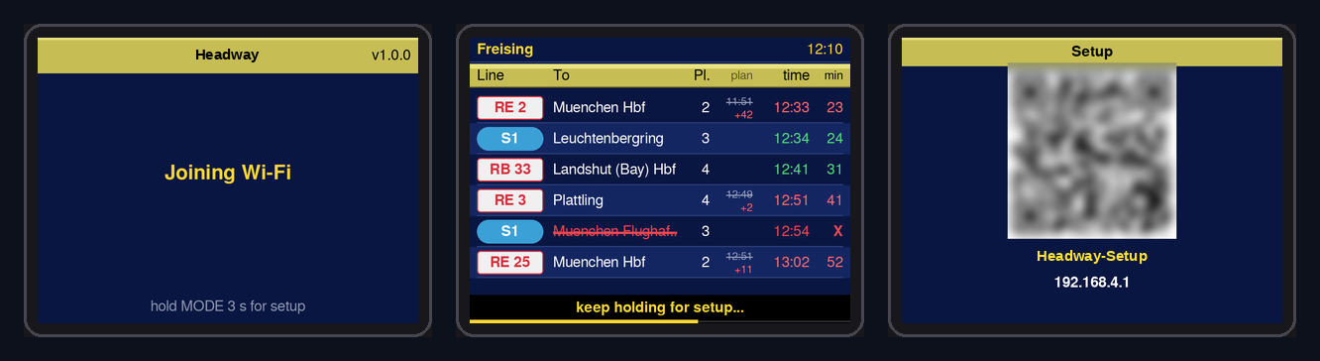
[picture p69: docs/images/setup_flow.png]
Boot, hold and setup examples


| Visible item or action | Meaning and reason |
| --- | --- |
| `Headway` and the version (e.g. `v1.2.8`) on startup | Project and installed firmware identity |
| Startup status line | Progress such as starting or joining Wi-Fi |
| Red last-restart information | Stored diagnostic reason, such as a power dip or watchdog reset; not a new weather/transport alert |
| Button tap | Advance exactly one page after debounce |
| Button held for about one second | Show `keep holding for setup...` |
| Yellow bar filling along the bottom during a running-screen hold | Progress from the one-second hint toward the three-second setup action |
| Release after the hint but before three seconds | Restore the current page without opening setup |
| Hold through three seconds | Enter setup; the button also works during the startup Wi-Fi join |
| RESET | Restart the board |
| `Setup` header | The device is showing setup instructions, not refreshing its normal boards |

The button is the physical BOOT button. Holding it while applying power or pressing RESET can enter
the chip's flashing/download mode and leave the display dark. Release it, reset, then start
the hold after the splash appears.

### Two different QR payloads

1. **Before a phone is connected:** the QR contains the setup network name and its password.
   It is a Wi-Fi-join shortcut; the password is not separately printed as text.
2. **After a device connects to the setup access point:** the same QR area changes to the
   local settings-page address. Scan again or browse to **http://192.168.4.1/**.

`Headway-Setup` identifies the setup Wi-Fi. The printed `192.168.4.1` is the local
setup address, not a public internet site. A red connection-error line explains a failed join
when present. Do not publish a photograph of your actual join QR if its embedded password
should stay private; documentation QR pictures are examples.

Setup opens on first use with no usable saved/fallback network, after startup cannot join,
or on the long hold. It does not expire on a timer. Save restarts the board; RESET exits by
restarting. The normal display mode does not offer the settings web server.

## Settings and examples

[See the setup portal broken into readable cards](index.html#setup) and the
[current device setup screen](previews_v1.2.6/O_8_setup.png).

| Setting or label | What it does and why |
| --- | --- |
| Network | Your 2.4 GHz Wi-Fi name; the ESP32-C3 cannot join 5 GHz-only networks |
| `Find networks` / `Scan again` | Scan for visible names; results are sorted strongest first |
| RSSI, e.g. `−50 dBm` | Received signal strength; −50 is stronger than −80, not a percentage |
| Password | Network password; blank keeps the stored password only when retaining the same network name |
| Typed hidden network name | Allows a direct join even if the name does not appear in scans |
| `In use now` | Currently resolved weather location; `(default)` indicates the fallback label |
| Detect automatically | Approximate location from the internet connection; VPN/provider routing may point elsewhere |
| Use this town | Look up the typed town after saving; check the resolved name on the weather page |
| Change pages automatically | Switch pages after the selected interval rather than only with the button |
| Time on each page | Default 10 seconds; standard options 5, 10, 15, 20, 30, 45 and 60 seconds |
| Scroll long destination names | Independently allows text to slide so more of a long name can be read (Split-Flap: turns over in parts) |
| Look | Original (default), Bahnsteig, Amber Matrix, Papier or Split-Flap; the board restarts into it after Save |
| Save and restart | Validate and store the configuration, then restart into normal mode |
| `Saving...` / disabled Save | A save attempt is underway; wait for its result |
| Saved/restarting confirmation | The board acknowledged the save; reconnect the phone to normal Wi-Fi |
| `No confirmation received...` | The browser did not confirm the outcome; check the board and reconnect before retrying |
| Start over | After a second confirmation, forgets the Wi-Fi, every setting and the delay graph and restarts into first-time setup in the Original look |
| Last unexpected restart with optional count | Helps identify repeated power or blocking problems; it is not a current network signal reading |

**Example:** keep manual page selection, turn on scrolling, and enter `Freising` as the weather
town. After Save, pages will still change only by the button, but long destinations can move. Choosing
a different weather town changes the forecast location, not the fixed Freising transport stops.

### Common questions

| Observation | Explanation / next step |
| --- | --- |
| Green train time but a blank delay graph | The row may be timetable-only; the graph requires usable realtime comparison |
| Green health dot but red delay bars | Fetching succeeded, while the returned trains were late |
| Grey coverage marker with green delay bar | Known delays are small, but some candidate services lack usable realtime comparison |
| Weather clock moves but data is old | The header clock is local time; check the footer time and health dot |
| `dry` next to a nonzero probability | No hourly bin crossed the wet-hour rule; “dry” is not a guarantee |
| An unexpected weather town | Automatic IP location or the first town-search match may differ from the intended place |
| Empty destination suffix or abbreviated text | Small-screen clipping; enable scrolling for the whole name |
| `nan` or an impossible value such as negative humidity | Incomplete upstream fields can expose an unavailable-value placeholder; it is not a valid measurement |
| History disappeared | It is RAM-only for train delay; restart clears it, then new observations fill it |
| Dark screen after holding BOOT during power-on | Release BOOT and press RESET, then hold only after startup begins |
| Frequent power-dip restart notices | Inspect the board's power supply, USB cable and wiring |

## Data limits and release status

Transport comes through [Transitous](https://transitous.org/); realtime availability and cancellations
depend on the underlying operators. Weather comes from [Open-Meteo](https://open-meteo.com/).
The device has no local weather sensor, GPS tracker, live vehicle-position display, official
service-alert system, touchscreen controls or audible departure alarm in this revision.

The configured station/stops are fixed in firmware. Forecast display time uses Europe/Berlin;
selecting a faraway weather town does not make this a general world-time display. Font space,
provider coverage and a small fixed departure buffer limit what can be shown. Consult official
operator information when a departure or cancellation matters.

Rev1.2 firmware 1.2.0 passed ESP32-C3 compile/link verification, 52 logic/graph assertions and
the setup-page JavaScript scenarios. Firmware 1.2.1–1.2.8 passed the same tests plus PC renders of
every screen in every look under memory checks, but has not yet been compiled for the ESP32 or
flashed. Tiny-icon legibility on the actual panel, overnight stability and enclosure fit remain
unverified. See the [release status](PROJECT_STATUS.md) for the first-flash checklist.

The original artwork, documentation and project material remain subject to the
[proprietary licence](../LICENSE) and [permission guide](PERMISSIONS.md).

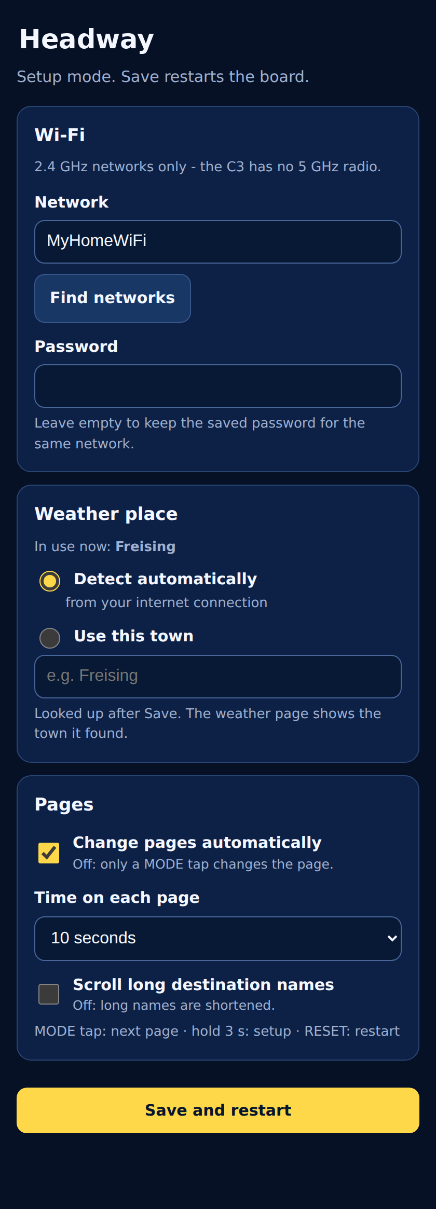
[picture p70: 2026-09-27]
docs/images/setup_page.png

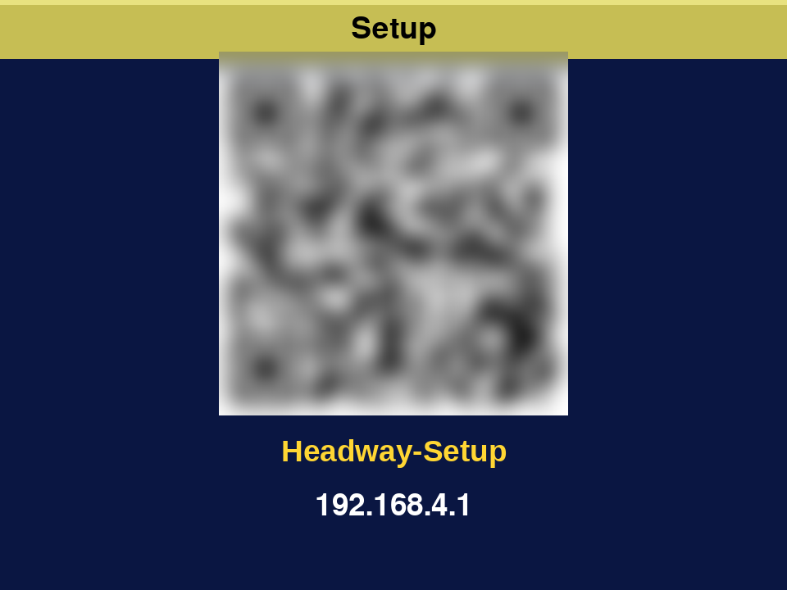
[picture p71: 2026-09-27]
docs/images/screen_setup.png

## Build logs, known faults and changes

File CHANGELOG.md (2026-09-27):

# Public showcase changelog

## Firmware 1.2.8 — 27 September 2026

- The outlook temperature graph now shows each day's low-to-high range across the last 30 days plus today. The left labels are the coldest low and warmest high; days without a low use a short mark.
- Added a public preview of the 1.2.8 graph and clarified that the phone photos and clips document the earlier powered prototype rather than proving a 1.2.8 flash.

## Rev1.2 refresh — 27 September 2026

- Reworked the README around why I built Headway and the everyday use I imagine by the mirror, front door and desk.
- Added a responsive project page with switchable previews for all five looks and the train, bus, weather, outlook and setup screens. The setup portal is explained in short, readable cards.
- Replaced the old Rev7 and planned desk-case sections with current Model A Rev9 and Model B rev2 FreeCAD sources, print files and isometric/front/back/top/side views. Added a stand view for Model B and actual printer-bed photos, labelled as such.
- Added the nine-wire pinout map and links to the ESP32-C3 and MSP3218 technical documents.
- Recast the 0.75 W electricity figure as an assumption pending a meter check. At that assumption, continuous use is 6.57 kWh/year; example cost is €1.97/year at €0.30/kWh.
- Updated ownership, repository links and permission notices to the Headway name. Hardware compile, flash and fit checks are still open.

## Firmware 1.2.7 — 27 September 2026

The three-hour train delay history now survives a software restart, with a gap for time spent restarting or in setup. Power removal and Start over clear it. The current firmware, tests and detailed changes are in [Headway_code](https://github.com/haldarsaurav/Headway_code).

## Rev1.1 — 25 September 2026

The feature and icon guide, corrected delay-history definition and reliability review were completed. The old release tags remain in the code repository's history.

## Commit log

2026-09-27 Refresh Headway showcase and mobile project page
    [DB_signboard_enclosure_rev7.FCStd, DB_signboard_enclosure_rev7.step, Headway_desk_rev2.FCStd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]
2026-09-27 Clarify display backlight wiring against vendor manual
2026-09-27 Refresh Headway showcase with prototype media and clearer navigation
2026-09-27 Update Headway showcase with prototype media and 1.2.8 guide
